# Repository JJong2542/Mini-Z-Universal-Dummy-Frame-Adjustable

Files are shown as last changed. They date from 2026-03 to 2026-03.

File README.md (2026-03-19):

# Mini-Z Universal Dummy Frame (90mm-102mm Adjustable)

Professional-grade adjustable dummy frame for Kyosho Mini-Z body fitting, painting, and display. This project provides high-precision engineering drawings for both CNC machining and 3D printing.

## 🚀 Key Features
- **Adjustable Wheelbase:** Supports 90mm, 94mm, 98mm, and 102mm setups.
- **Wide/Narrow Compatible:** Designed to verify fitment for both standard and wide-body kits (e.g., HRC Wide Body).
- **Manufacturing Ready:** Includes full technical drawings (PDF) with tolerances for AL6061 CNC machining.
- **Surface Finish:** Optimized for sanded black gloss anodizing.

## 📂 Project Structure
- `/3D Print`: Full set 3D Printed 'STL Format File' (Parts).
- `/STEP File`: Full set 3D Cad Data 'STEP Format File' (Part Data).
- `/Drawings`: Full set of technical drawings (Assembly & Part Drawings).
- `/Photos`: Verified 3D printed samples and body fitting examples (Toyota 86).

## 🛠 Specifications
- **Material:** AL6061 (Aluminum) or 3D Printing (PLA/PETG/Resin)
- **Hardware:** M2 Bolts & Taps
- **Compatibility:** All Kyosho Mini-Z AWD/FWD wheelbases

## 📸 Proof of Concept

| 94mm Setup (Toyota 86)_Top | 94mm Setup (Toyota 86)_Under |
| :---: | :---: |
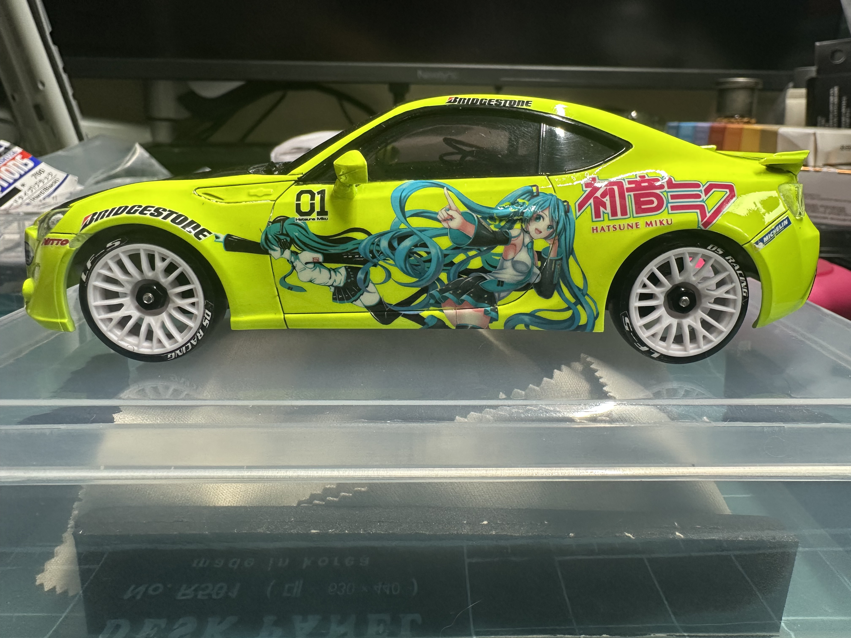
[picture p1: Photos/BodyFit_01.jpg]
Toyota 86 Fitting_01
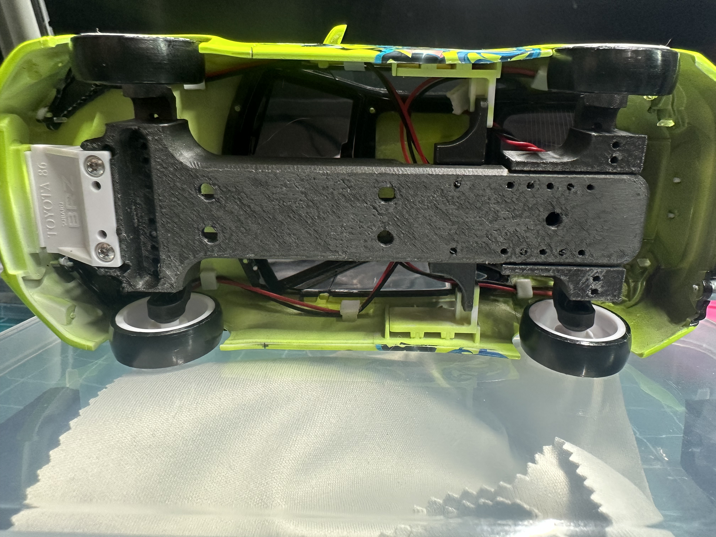
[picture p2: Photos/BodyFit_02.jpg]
Toyota 86 Fitting_02
|  |  |

| 3D Printed Sample_Top | 3D Printed Sample_Under |
| :---: | :---: |
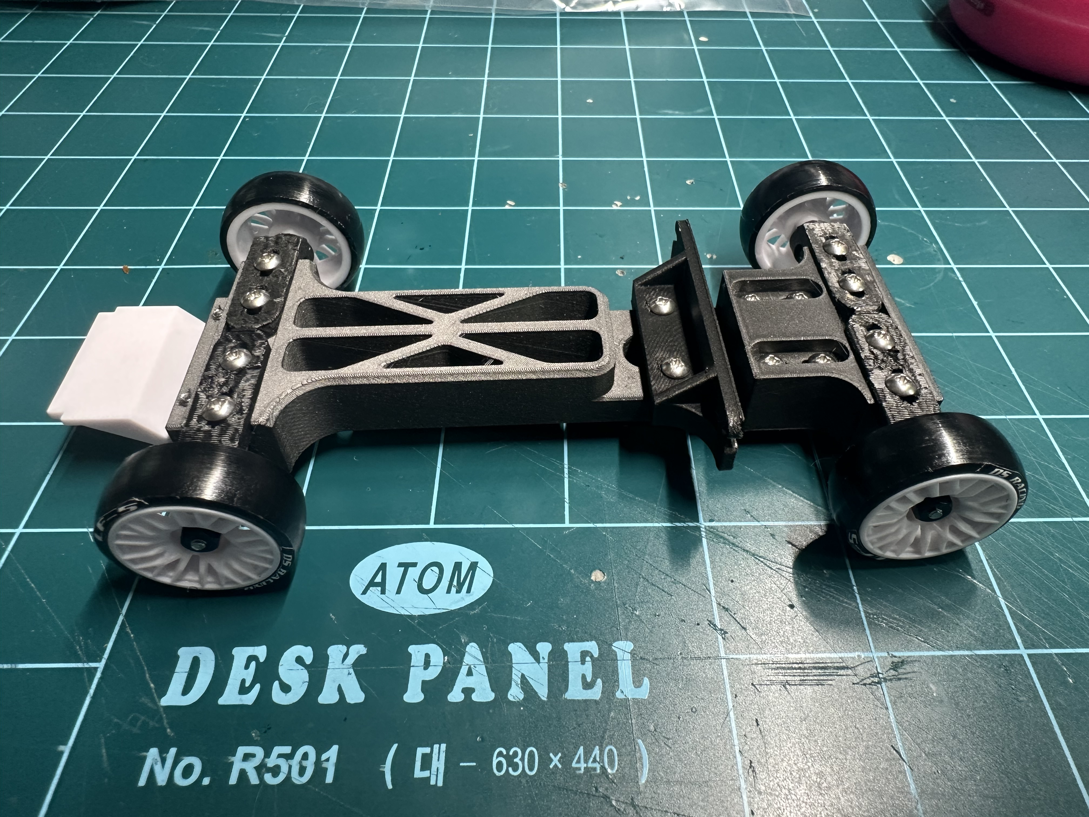
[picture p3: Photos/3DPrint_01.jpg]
3D Sample_01
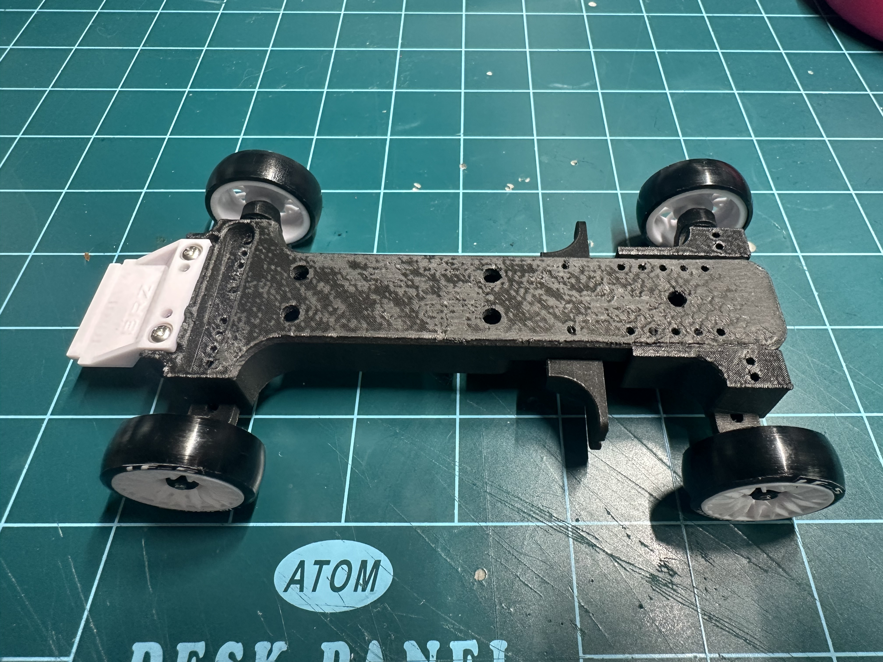
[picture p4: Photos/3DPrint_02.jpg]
3D Sample_02
|  |  |

### Functional Preview
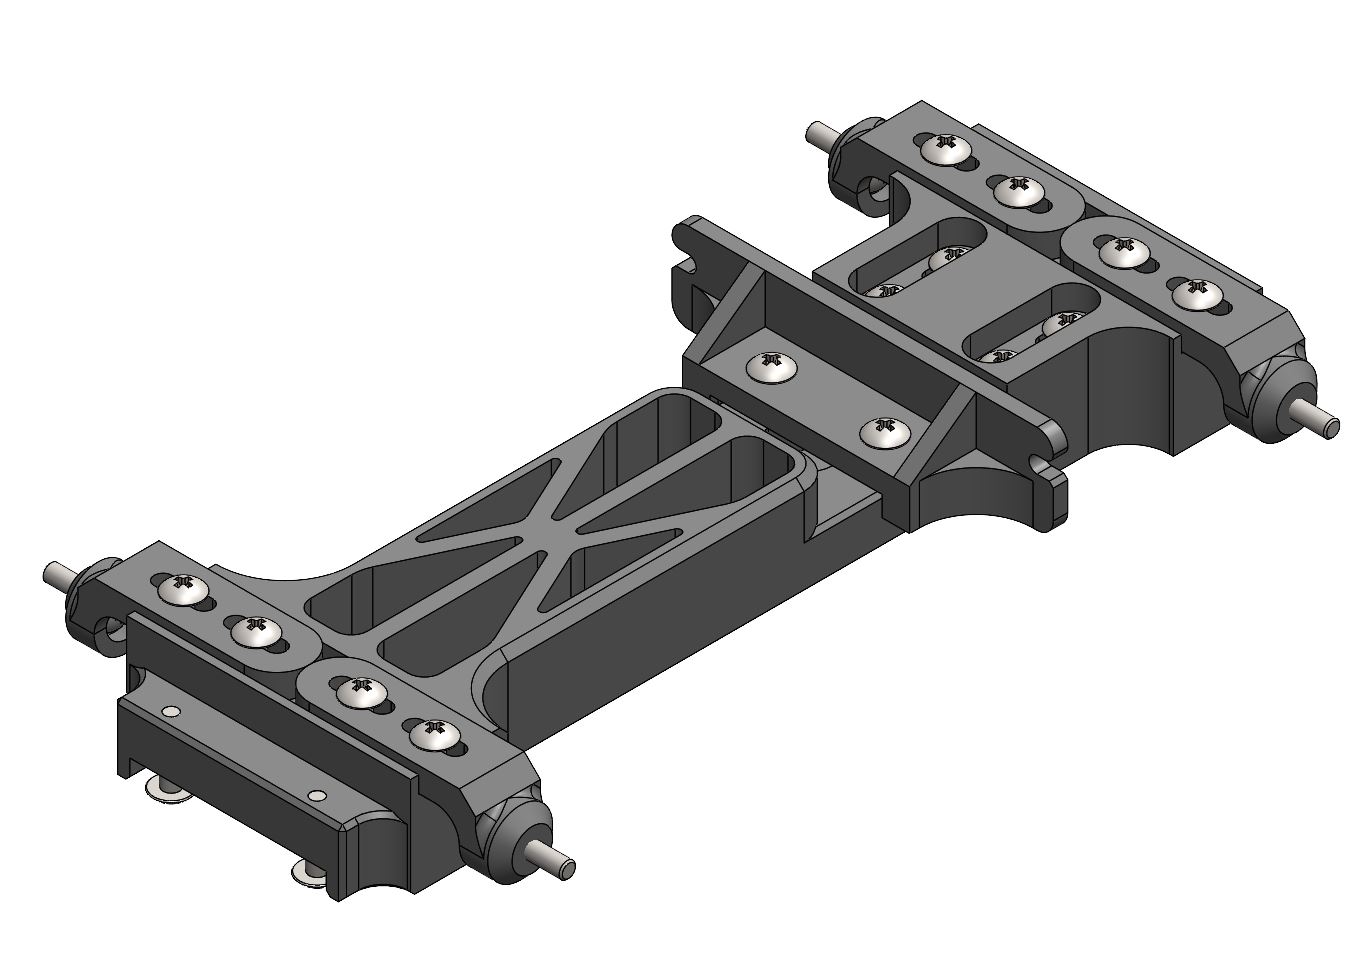
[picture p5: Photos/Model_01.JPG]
Dummy Frame Layout_01

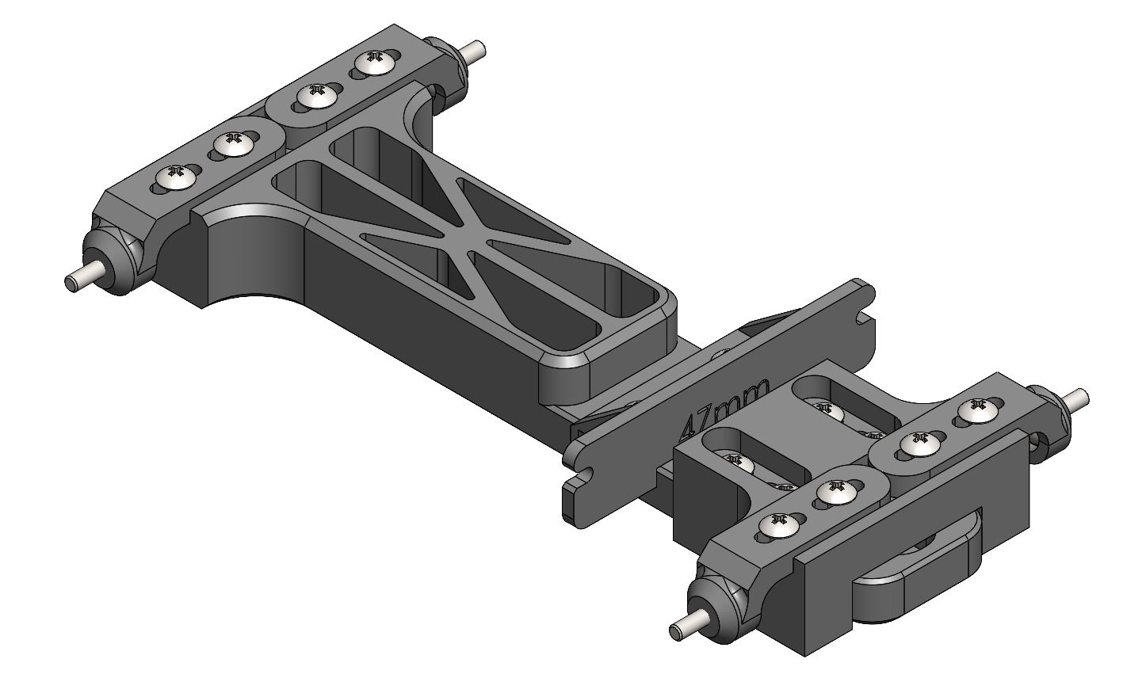
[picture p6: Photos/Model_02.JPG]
Dummy Frame Layout_02


## 🛠️ Assembly & Setup Guide

To help you get started quickly, please refer to the assembly layout and setup sheet below:

### 1. Assembly Layout
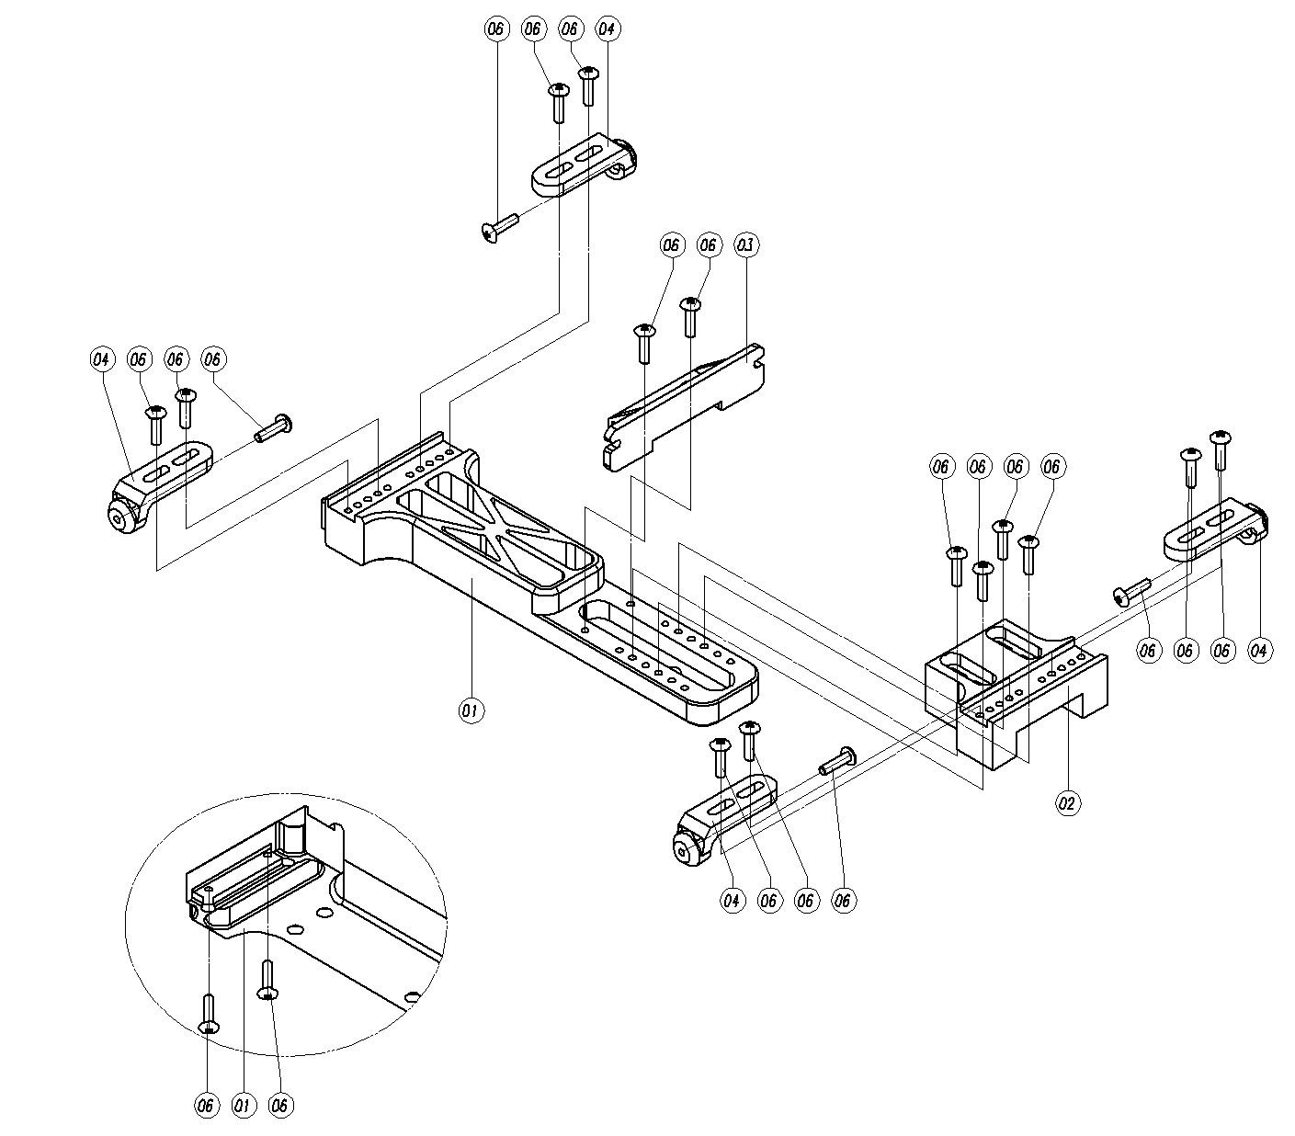
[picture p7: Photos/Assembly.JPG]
Assembly Guide

*Exploded view for clear component positioning.*
### 2. Parts List (BOM)
| Number | Part Name | Drawing Number | Quantity |
| :--- | :--- | :--- | :--- |
| 1 | **Main Body** | `F01-0002-01` | 1 |
| 2 | **Rear Wheel Mount** | `F01-0003-01` | 1 |
| 3 | **Body Mount** | `F01-0004-01` | 1 |
| 4 | **Wheel Hub** | `F01-0001-01` | 4 |
| 5 | **Post** | `F01-0005-01` | 3 |
| 6 | **Screw** | `Truss M2 X 8L` | 20 |

> [!NOTE]
> All mechanical parts are designed for M2 screws. For 3D printing, it is recommended to have a 2.0mm tap or drill bit ready for clean assembly.

### 3. Setup Sheet (Wheelbase & Width)
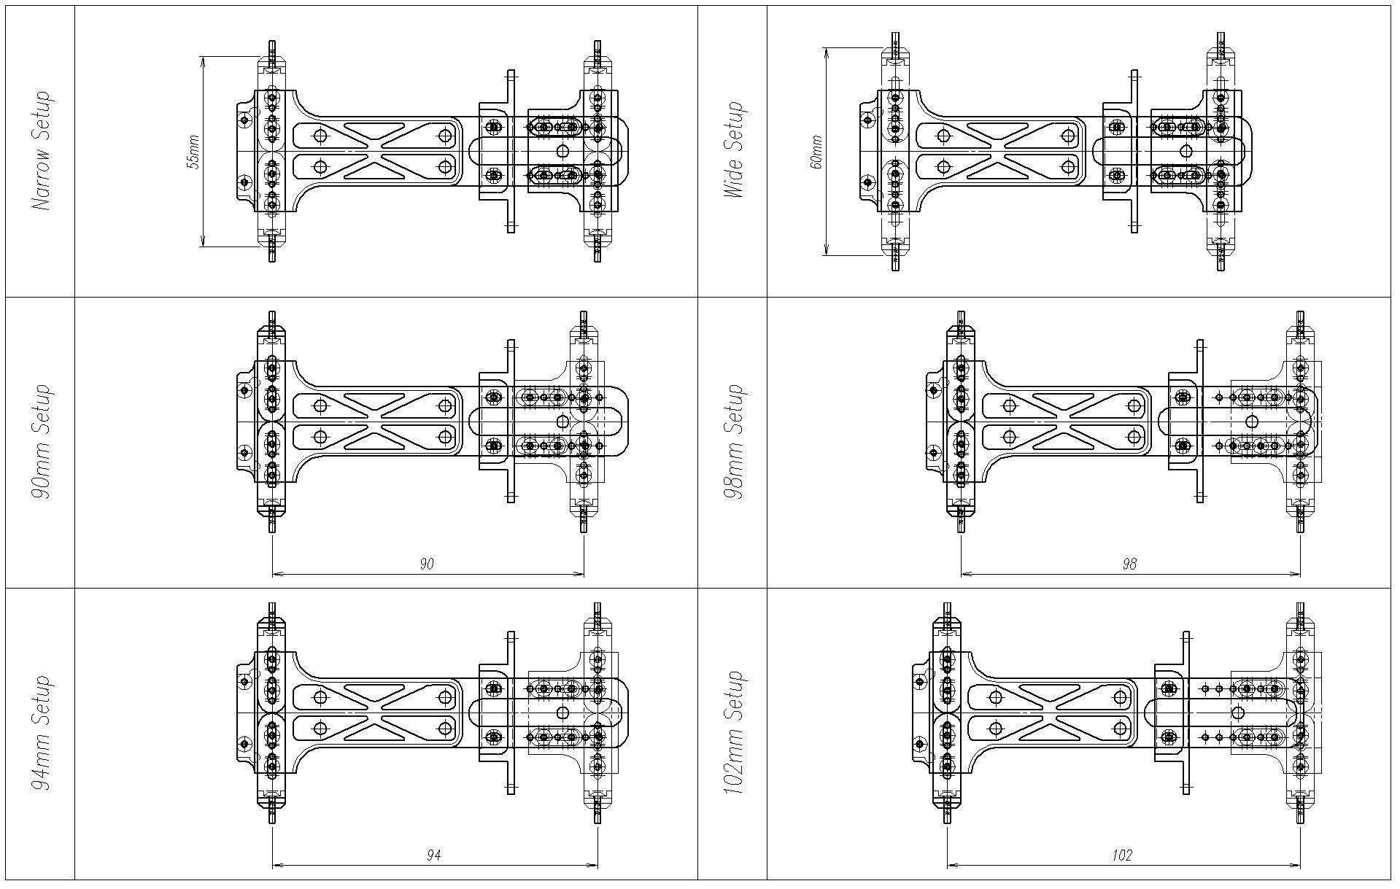
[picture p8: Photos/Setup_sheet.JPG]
Setup Sheet

*Quick reference for 90mm, 94mm, 98mm, and 102mm configurations.*

## ⚖️ License
This project is shared for the Mini-Z community. Feel free to use, modify, and share.

---
**Designed by JWKim**
*Precision Mechanical Design for RC Enthusiasts*

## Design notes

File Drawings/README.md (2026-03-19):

## 📄 Available Drawings
All drawings are provided in **PDF format** with full dimensions and tolerances:
- `F01-1001-01`: Assembly Drawing (Standard & ISO)
- `F01-0001-01`: Wheel Hub
- `F01-0002-01`: Main Base
- `F01-0003-01`: Rear Wheel Mount
- `F01-0004-01`: Body Mount
- `F01-0005-01`: Post

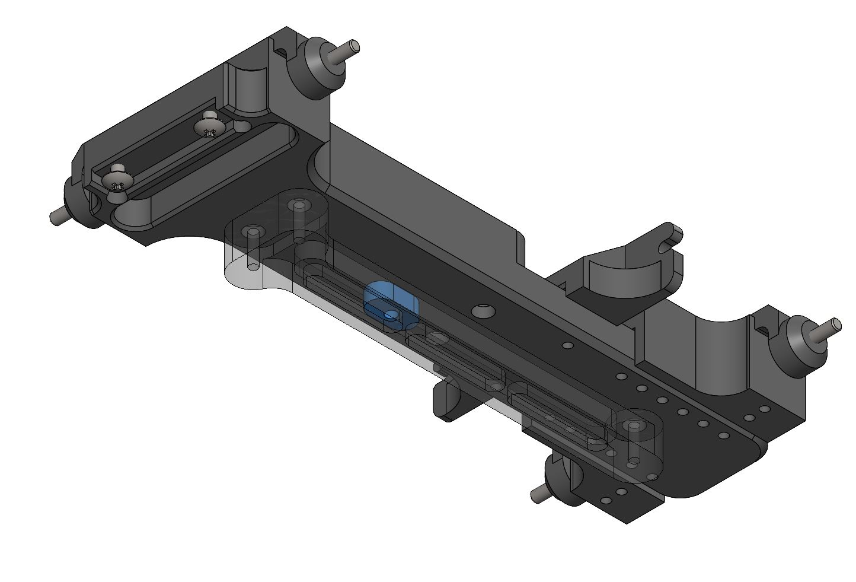
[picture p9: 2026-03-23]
Photos/Model_04.JPG

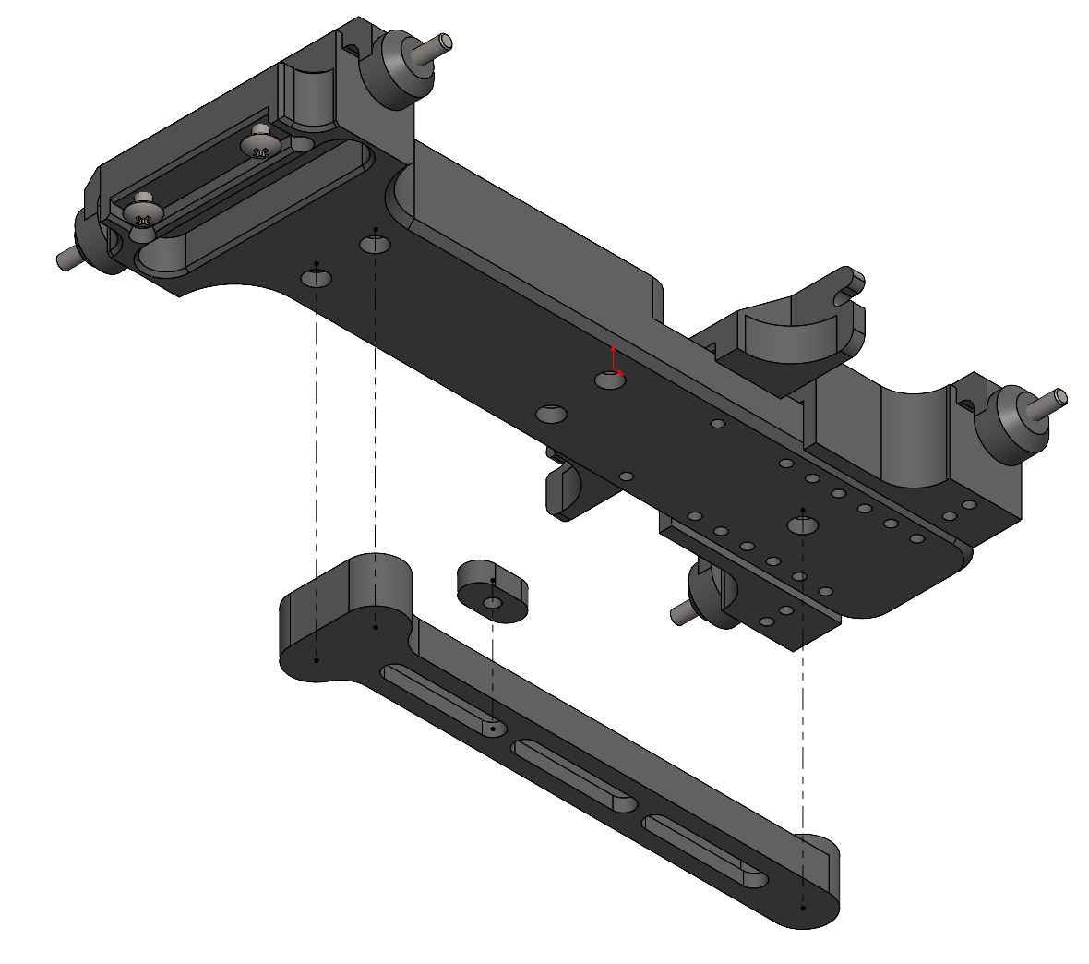
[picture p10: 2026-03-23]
Photos/Model_03.JPG

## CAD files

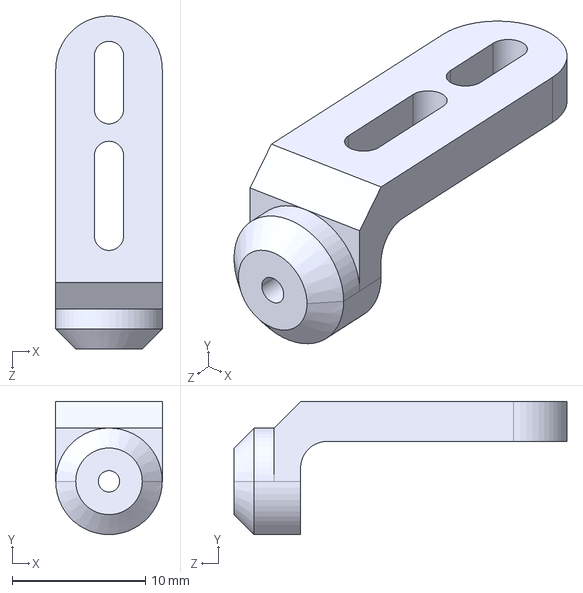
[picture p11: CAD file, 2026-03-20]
STEP File/F01-0001-02.STEP
8.00 x 10.0 x 25.0 mm

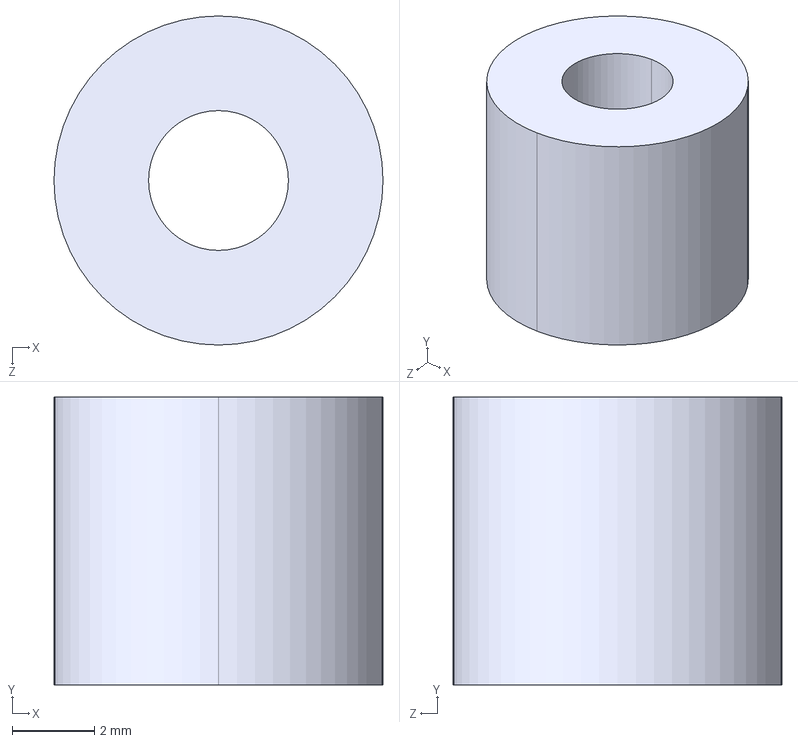
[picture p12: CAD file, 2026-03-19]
STEP File/F01-0005-01.STEP
8.00 x 7.00 x 8.00 mm

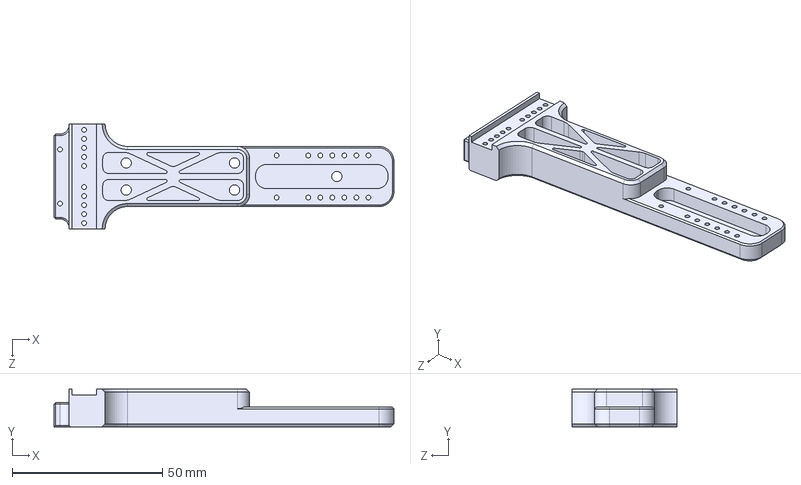
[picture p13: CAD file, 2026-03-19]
STEP File/F01-0002-01.STEP
113.0 x 12.5 x 35.0 mm

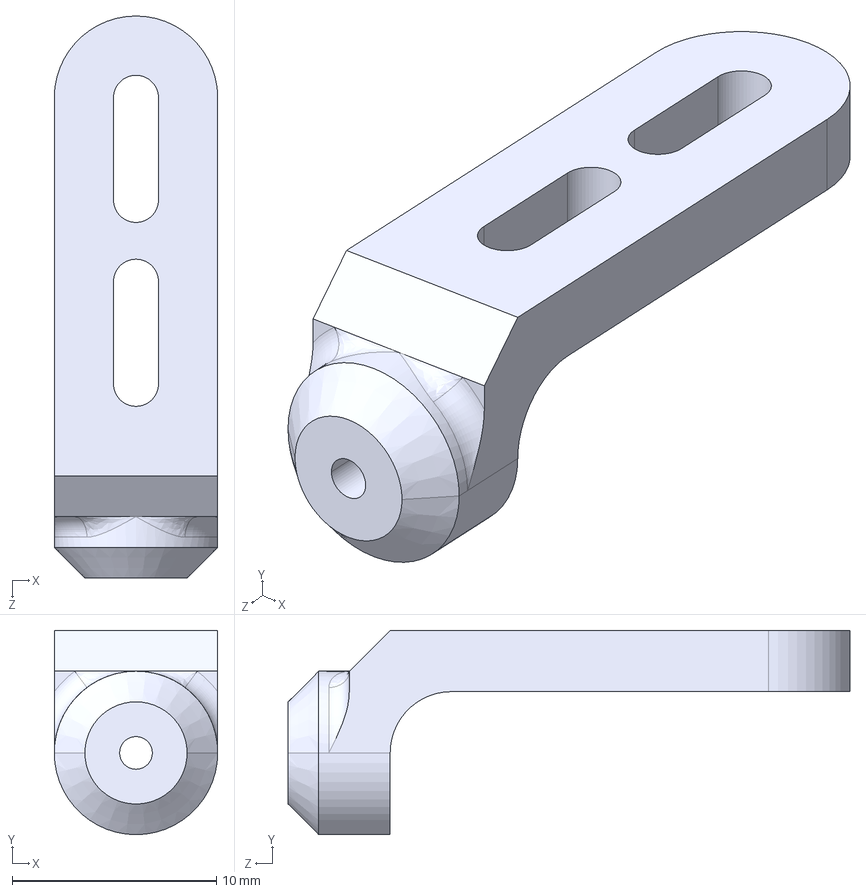
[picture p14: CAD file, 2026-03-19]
STEP File/F01-0001-01.STEP
8.00 x 10.0 x 27.5 mm

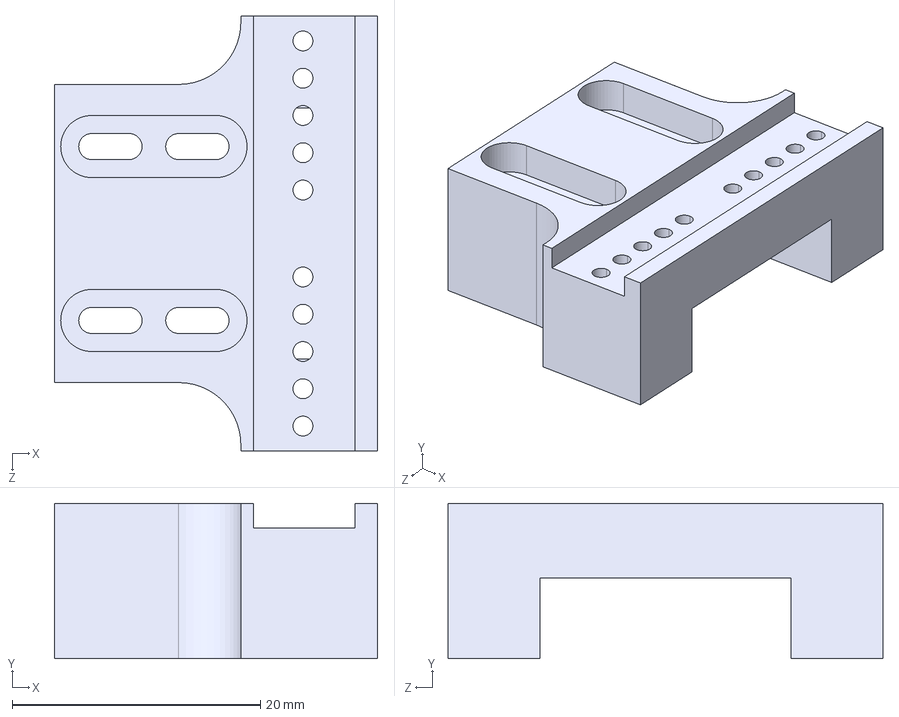
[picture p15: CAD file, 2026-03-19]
STEP File/F01-0003-01.STEP
26.0 x 12.5 x 35.0 mm

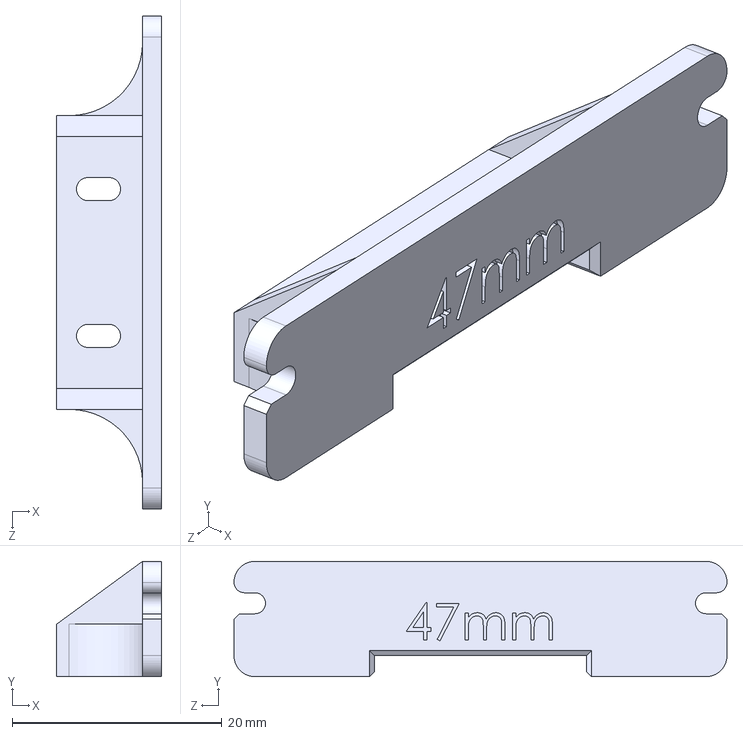
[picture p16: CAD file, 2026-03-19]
STEP File/F01-0004-03_47mm.STEP
10.0 x 11.0 x 47.0 mm

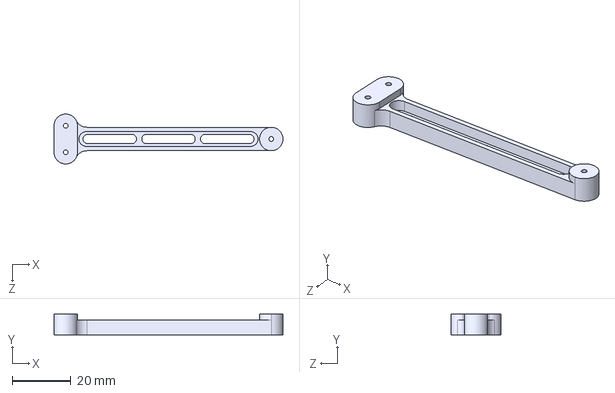
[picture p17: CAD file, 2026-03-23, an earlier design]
STEP File/Legacy_1.2/F01-0006-01.STEP
78.0 x 7.00 x 17.0 mm

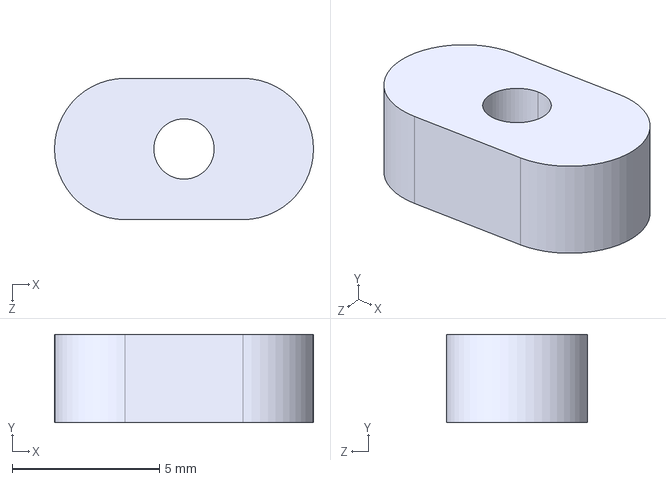
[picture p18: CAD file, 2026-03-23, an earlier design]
STEP File/Legacy_1.2/F01-0005-02.STEP
8.80 x 3.00 x 4.80 mm

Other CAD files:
3D_Print/F01-0001-01.STL
3D_Print/F01-0001-02.STL
3D_Print/F01-0002-01.STL
3D_Print/F01-0003-01.STL
3D_Print/F01-0004-03_47mm.STL
3D_Print/F01-0005-01.STL
3D_Print/Legacy_1.1/F01-0001-01.STL
3D_Print/Legacy_1.1/F01-0005-01.STL
3D_Print/Legacy_1.2/F01-0001-02.STL
3D_Print/Legacy_1.2/F01-0002-01.STL
3D_Print/Legacy_1.2/F01-0003-01.STL
3D_Print/Legacy_1.2/F01-0004-03_47mm.STL
3D_Print/Legacy_1.2/F01-0005-02.STL
3D_Print/Legacy_1.2/F01-0006-01.STL

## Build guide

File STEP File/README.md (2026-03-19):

## 📐 CAD Collaboration (STEP Files)
For advanced users and engineers, I have included **STEP files** to allow for easy modification and integration. 

- **Full Assembly Control:** Use the `.step` files to verify fits in your own CAD environment.
- **Customization:** Feel free to modify the design to create your own custom mounts or specialized jigs.
- **High Compatibility:** Compatible with all major CAD software including Fusion 360, SolidWorks, CATIA, and Rhino.

> [!TIP]
> If you create a derivative work or an improved version based on these STEP files, I’d love to see it! Please feel free to share your results with the community.

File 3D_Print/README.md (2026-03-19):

## 🖨️ 3D Printing (STL Files)
For those who don't have access to CNC machining, I've provided **STL files** for 3D printing.

### Recommended Print Settings
- **Material:** PETG or ABS (Recommended for durability), PLA+ is also fine.
- **Infill:** 40% or higher (Grid or Gyroid pattern for strength).
- **Wall Line Count:** 3-4 layers.
- **Support:** Required for some parts (Main Base and Rear Wheel Mount).
- **Layer Height:** 0.16mm - 0.2mm.

### Assembly Note
- Since 3D prints have slight shrinkage, you might need to clean up the holes with a **2mm drill bit** or a **reamer** for a perfect fit with the M2 bolts.
> **Tip:** You can view the 3D models directly in your browser! Just click on any `.stl` file in the `STL` folder to rotate and inspect the design before downloading.

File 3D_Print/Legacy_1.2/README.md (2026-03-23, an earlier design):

This folder contains data from the previous version, 1.2.

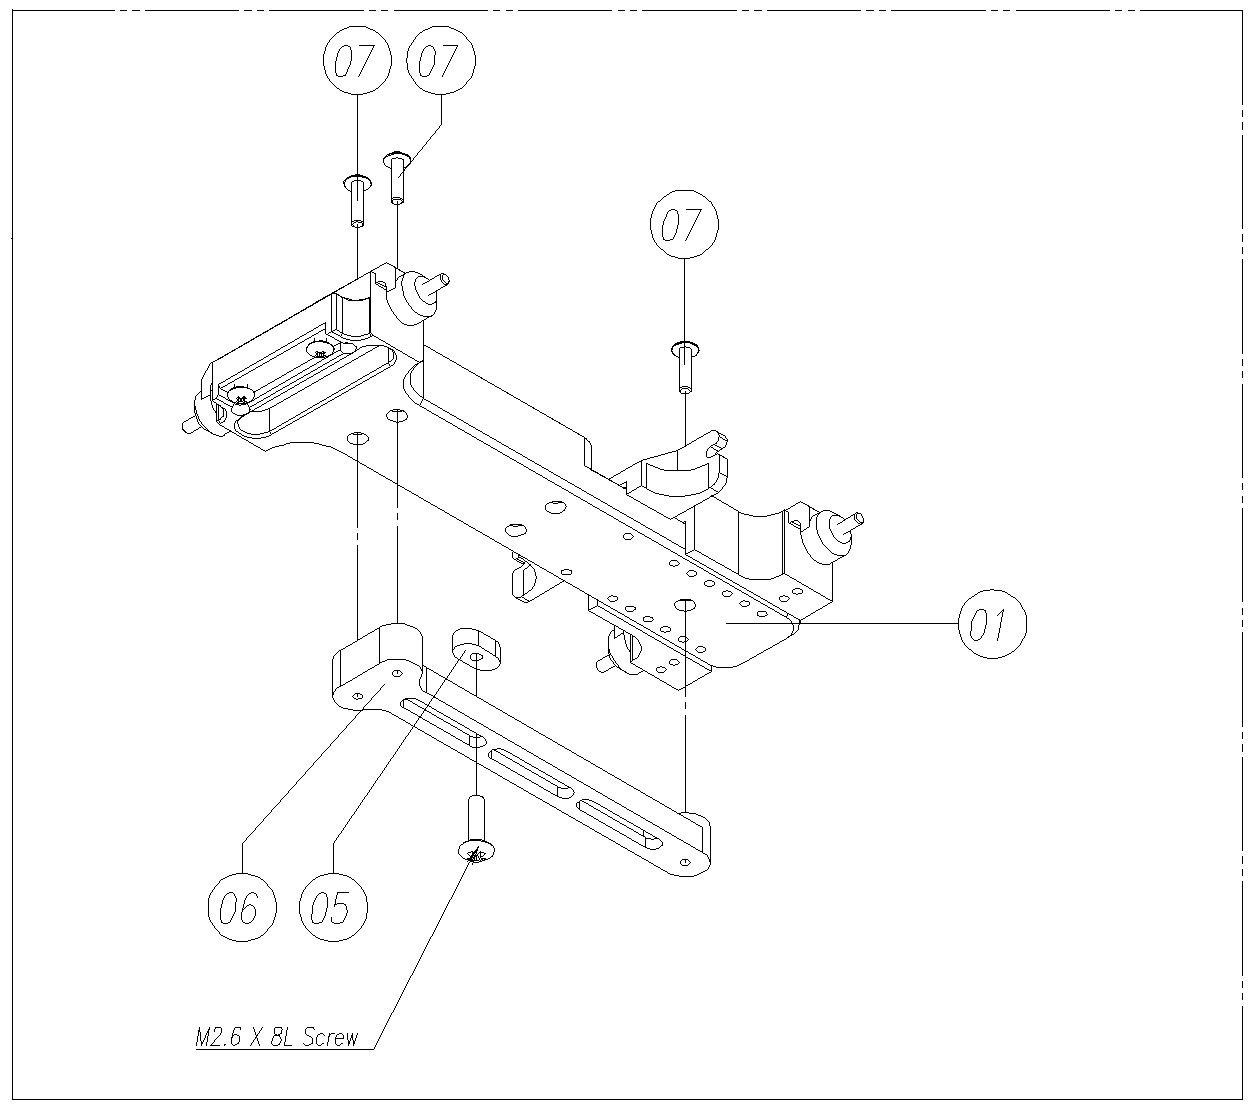
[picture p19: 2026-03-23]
Photos/Setup_sheet_02.JPG

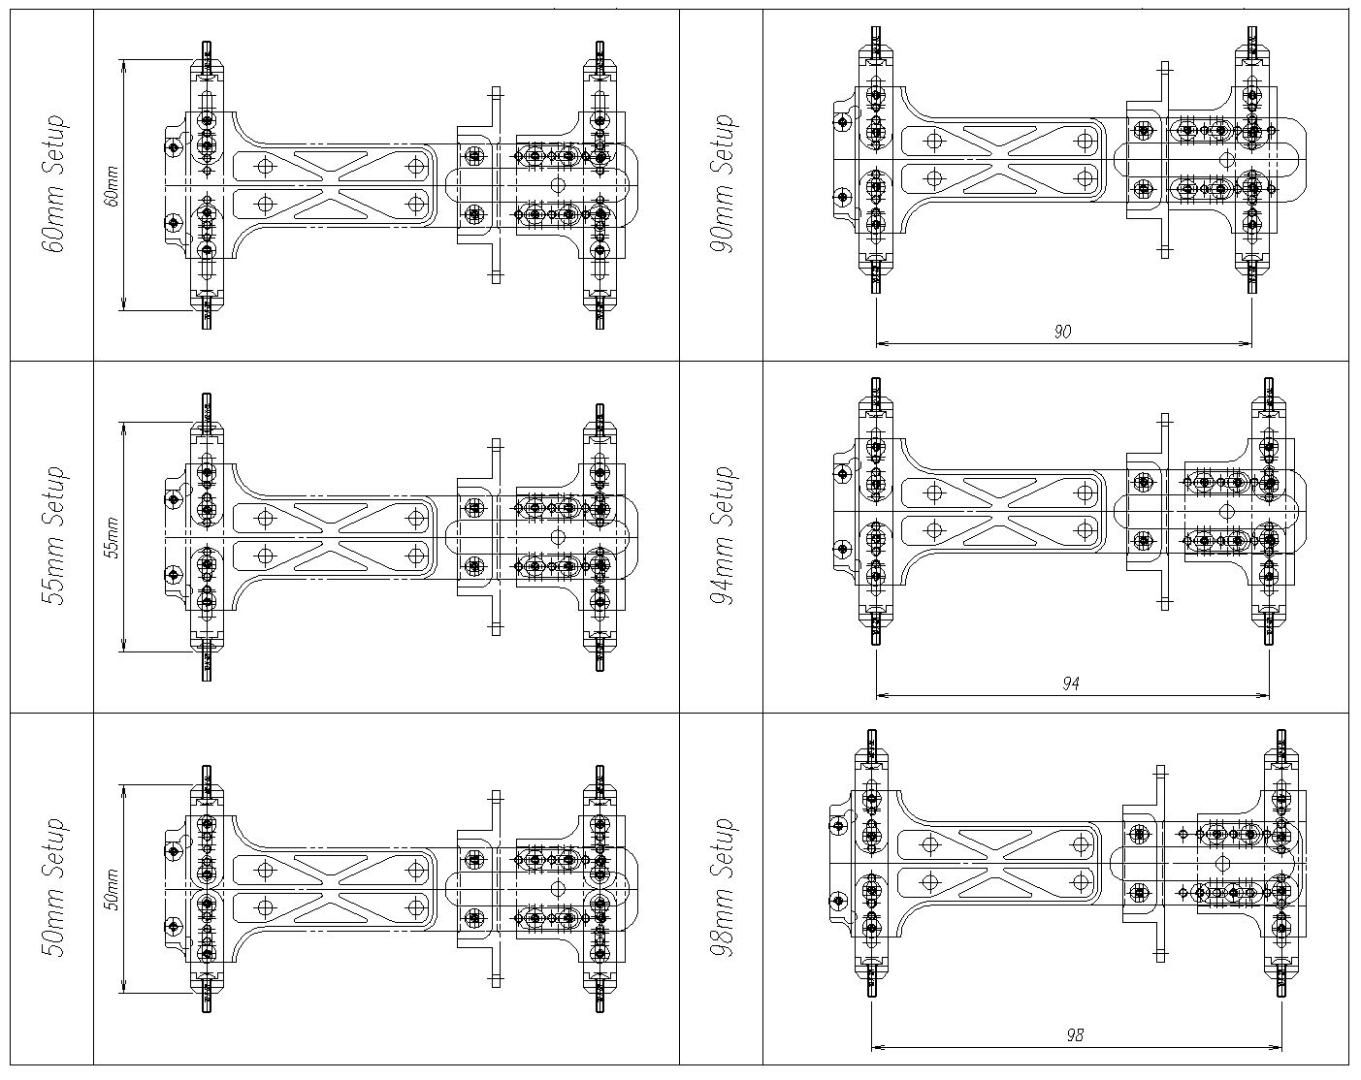
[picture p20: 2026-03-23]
Photos/Setup_sheet_01.JPG

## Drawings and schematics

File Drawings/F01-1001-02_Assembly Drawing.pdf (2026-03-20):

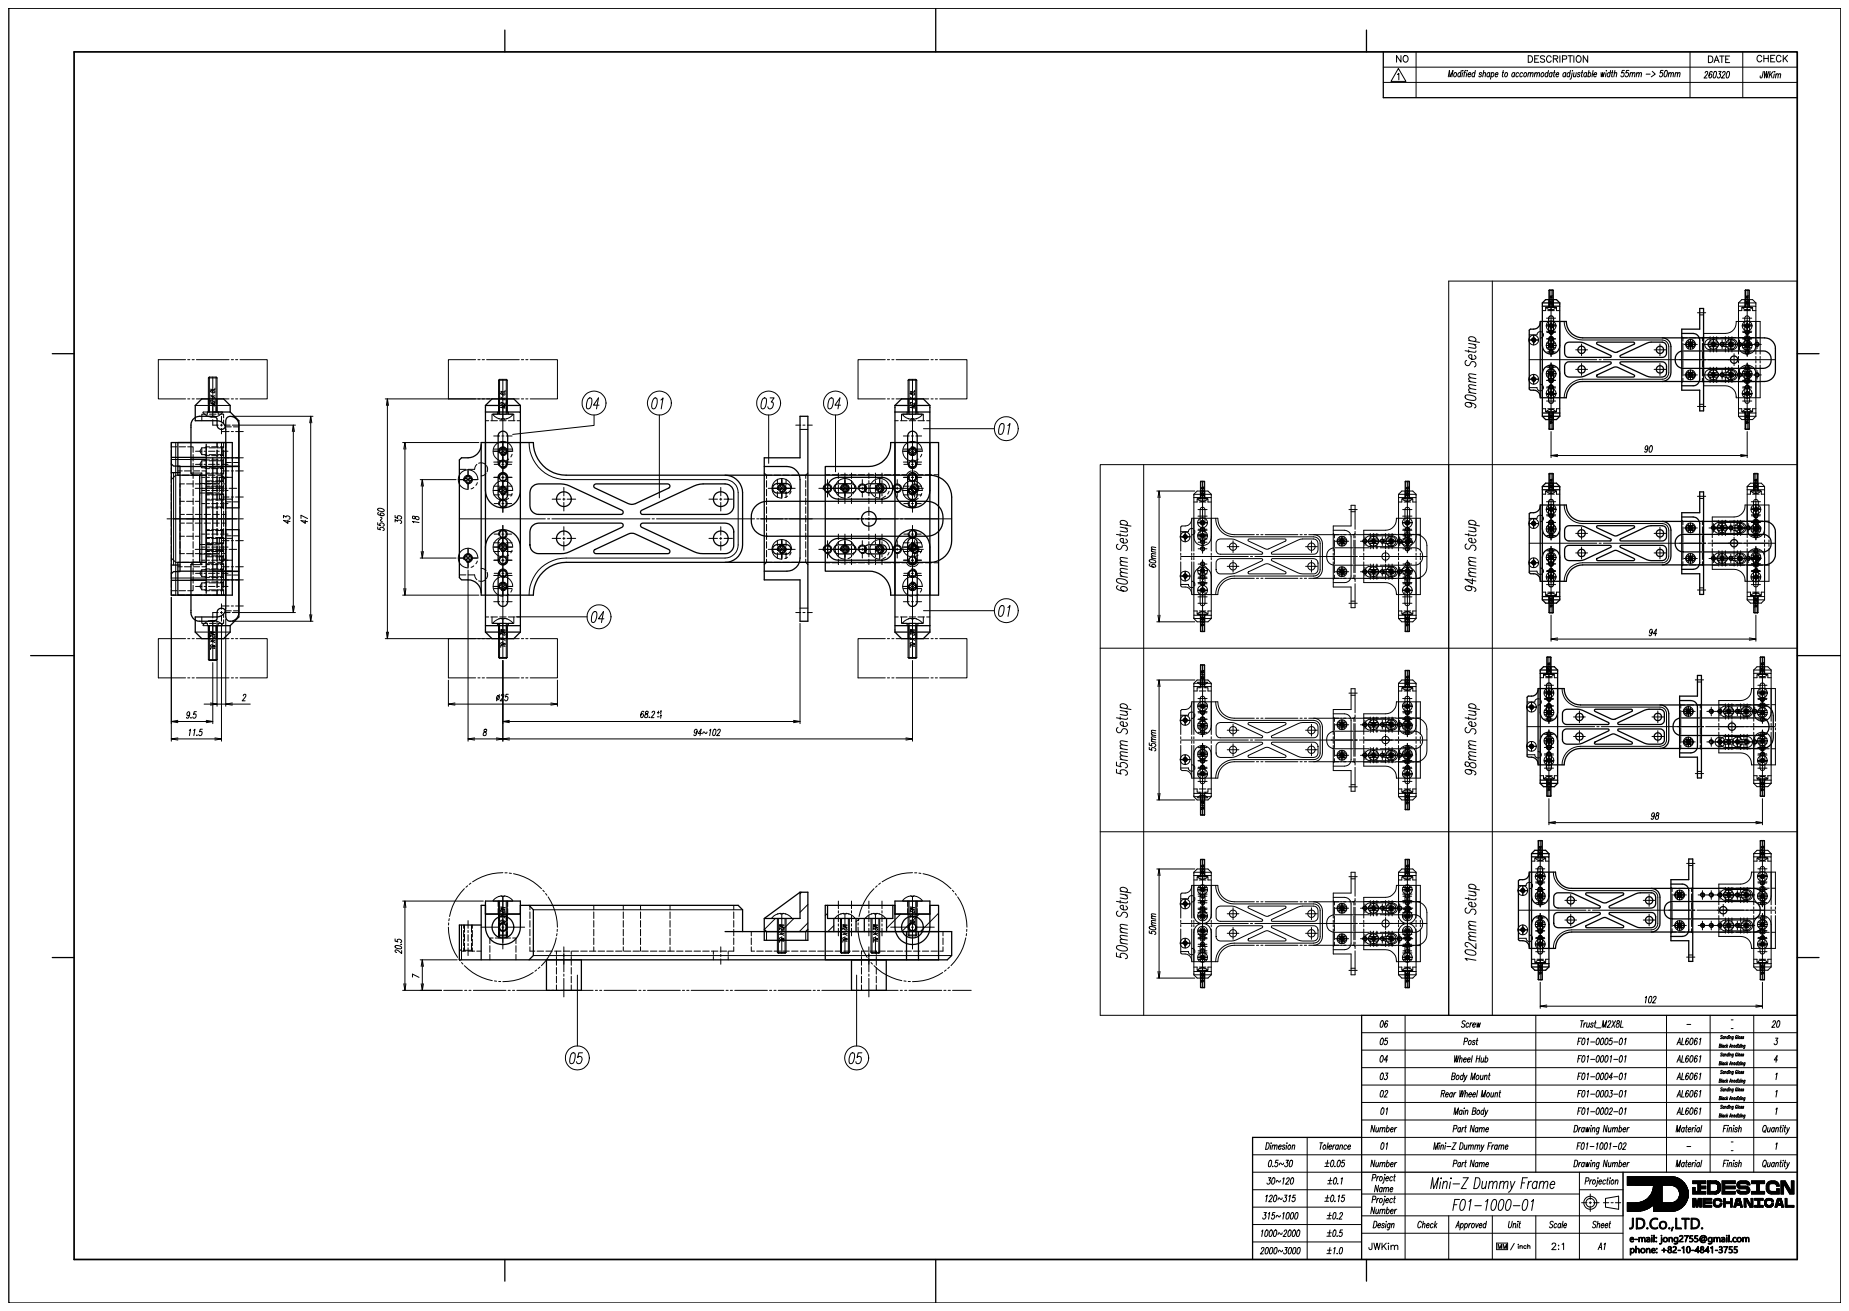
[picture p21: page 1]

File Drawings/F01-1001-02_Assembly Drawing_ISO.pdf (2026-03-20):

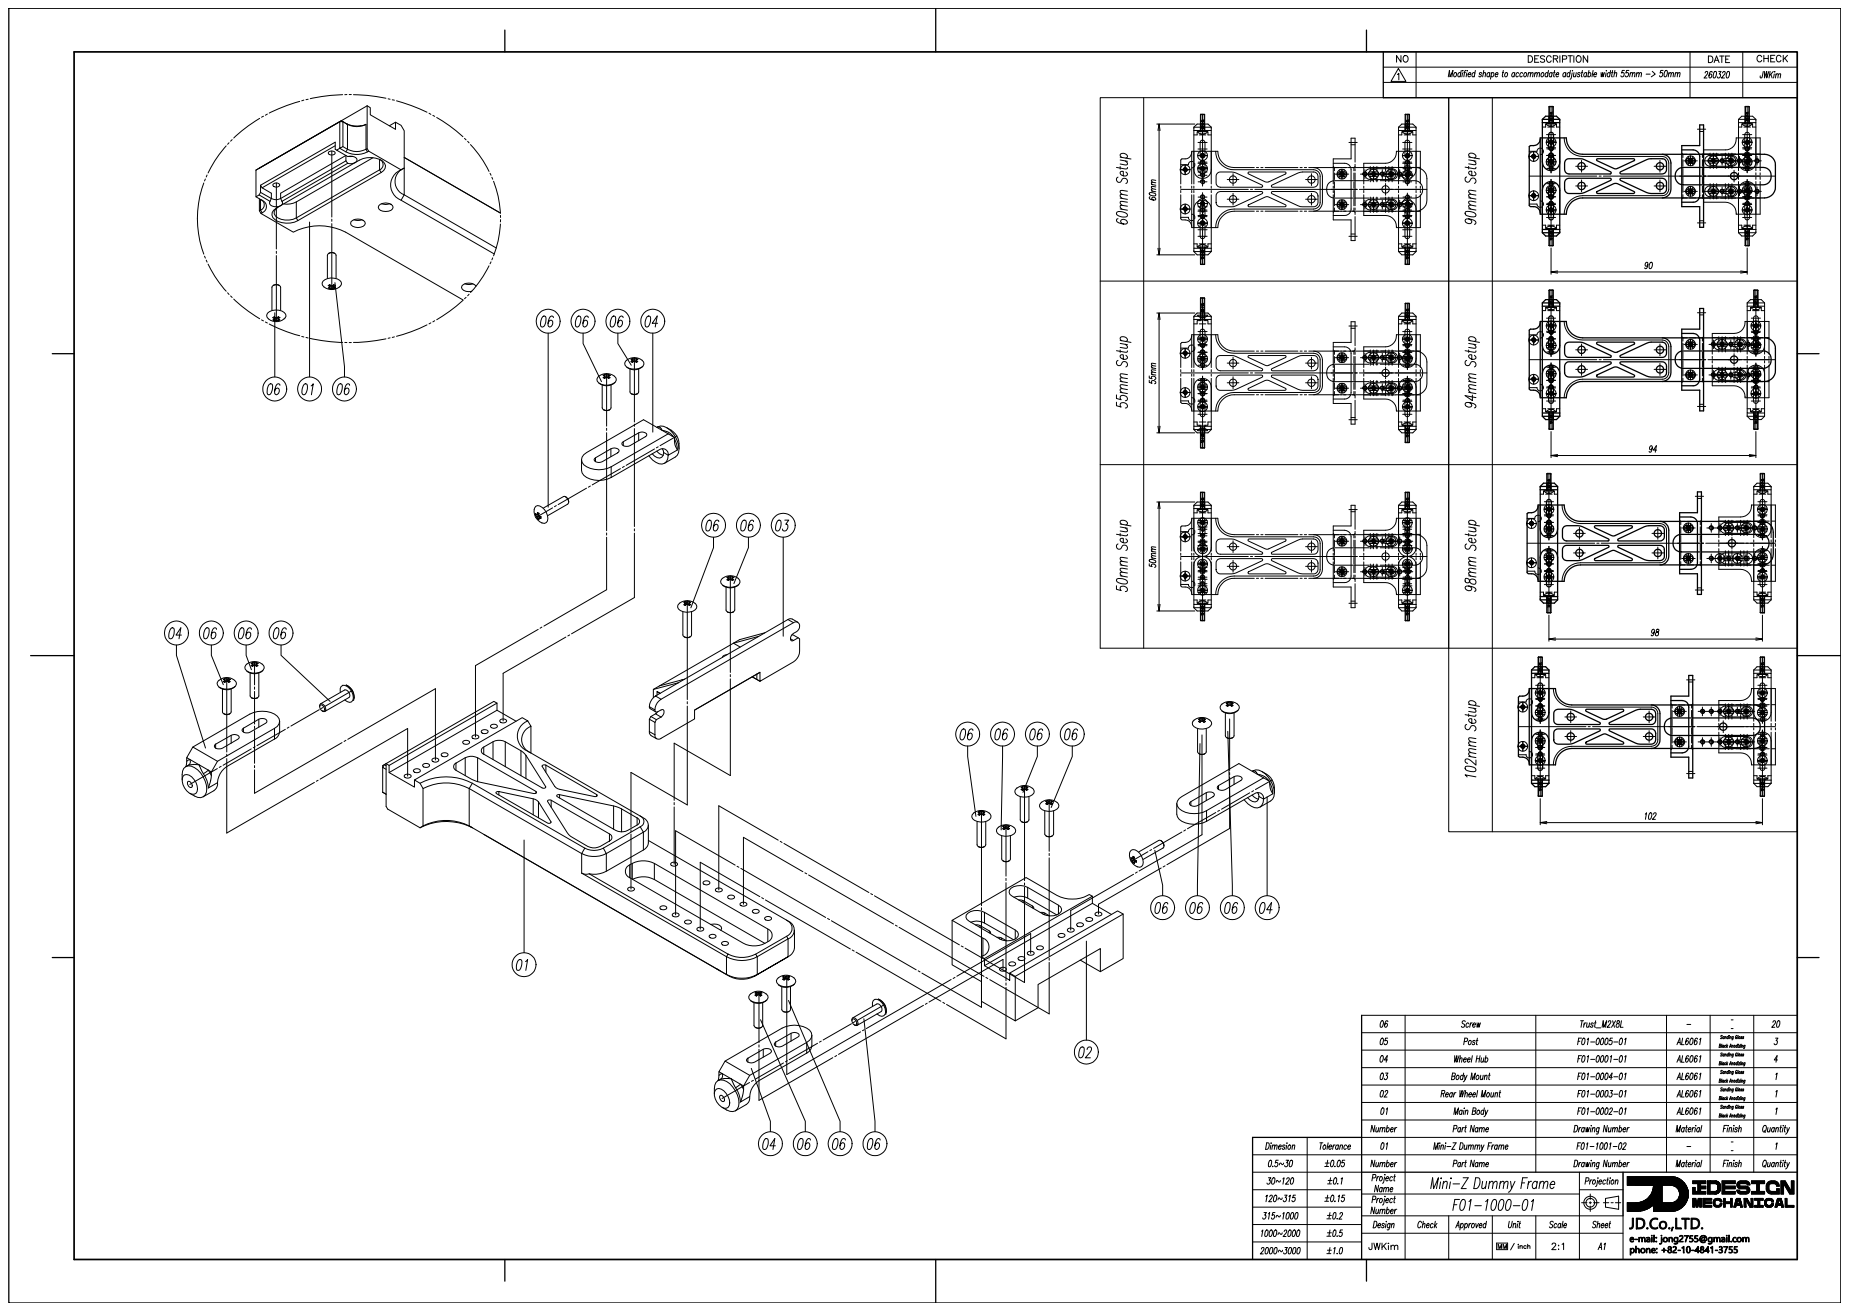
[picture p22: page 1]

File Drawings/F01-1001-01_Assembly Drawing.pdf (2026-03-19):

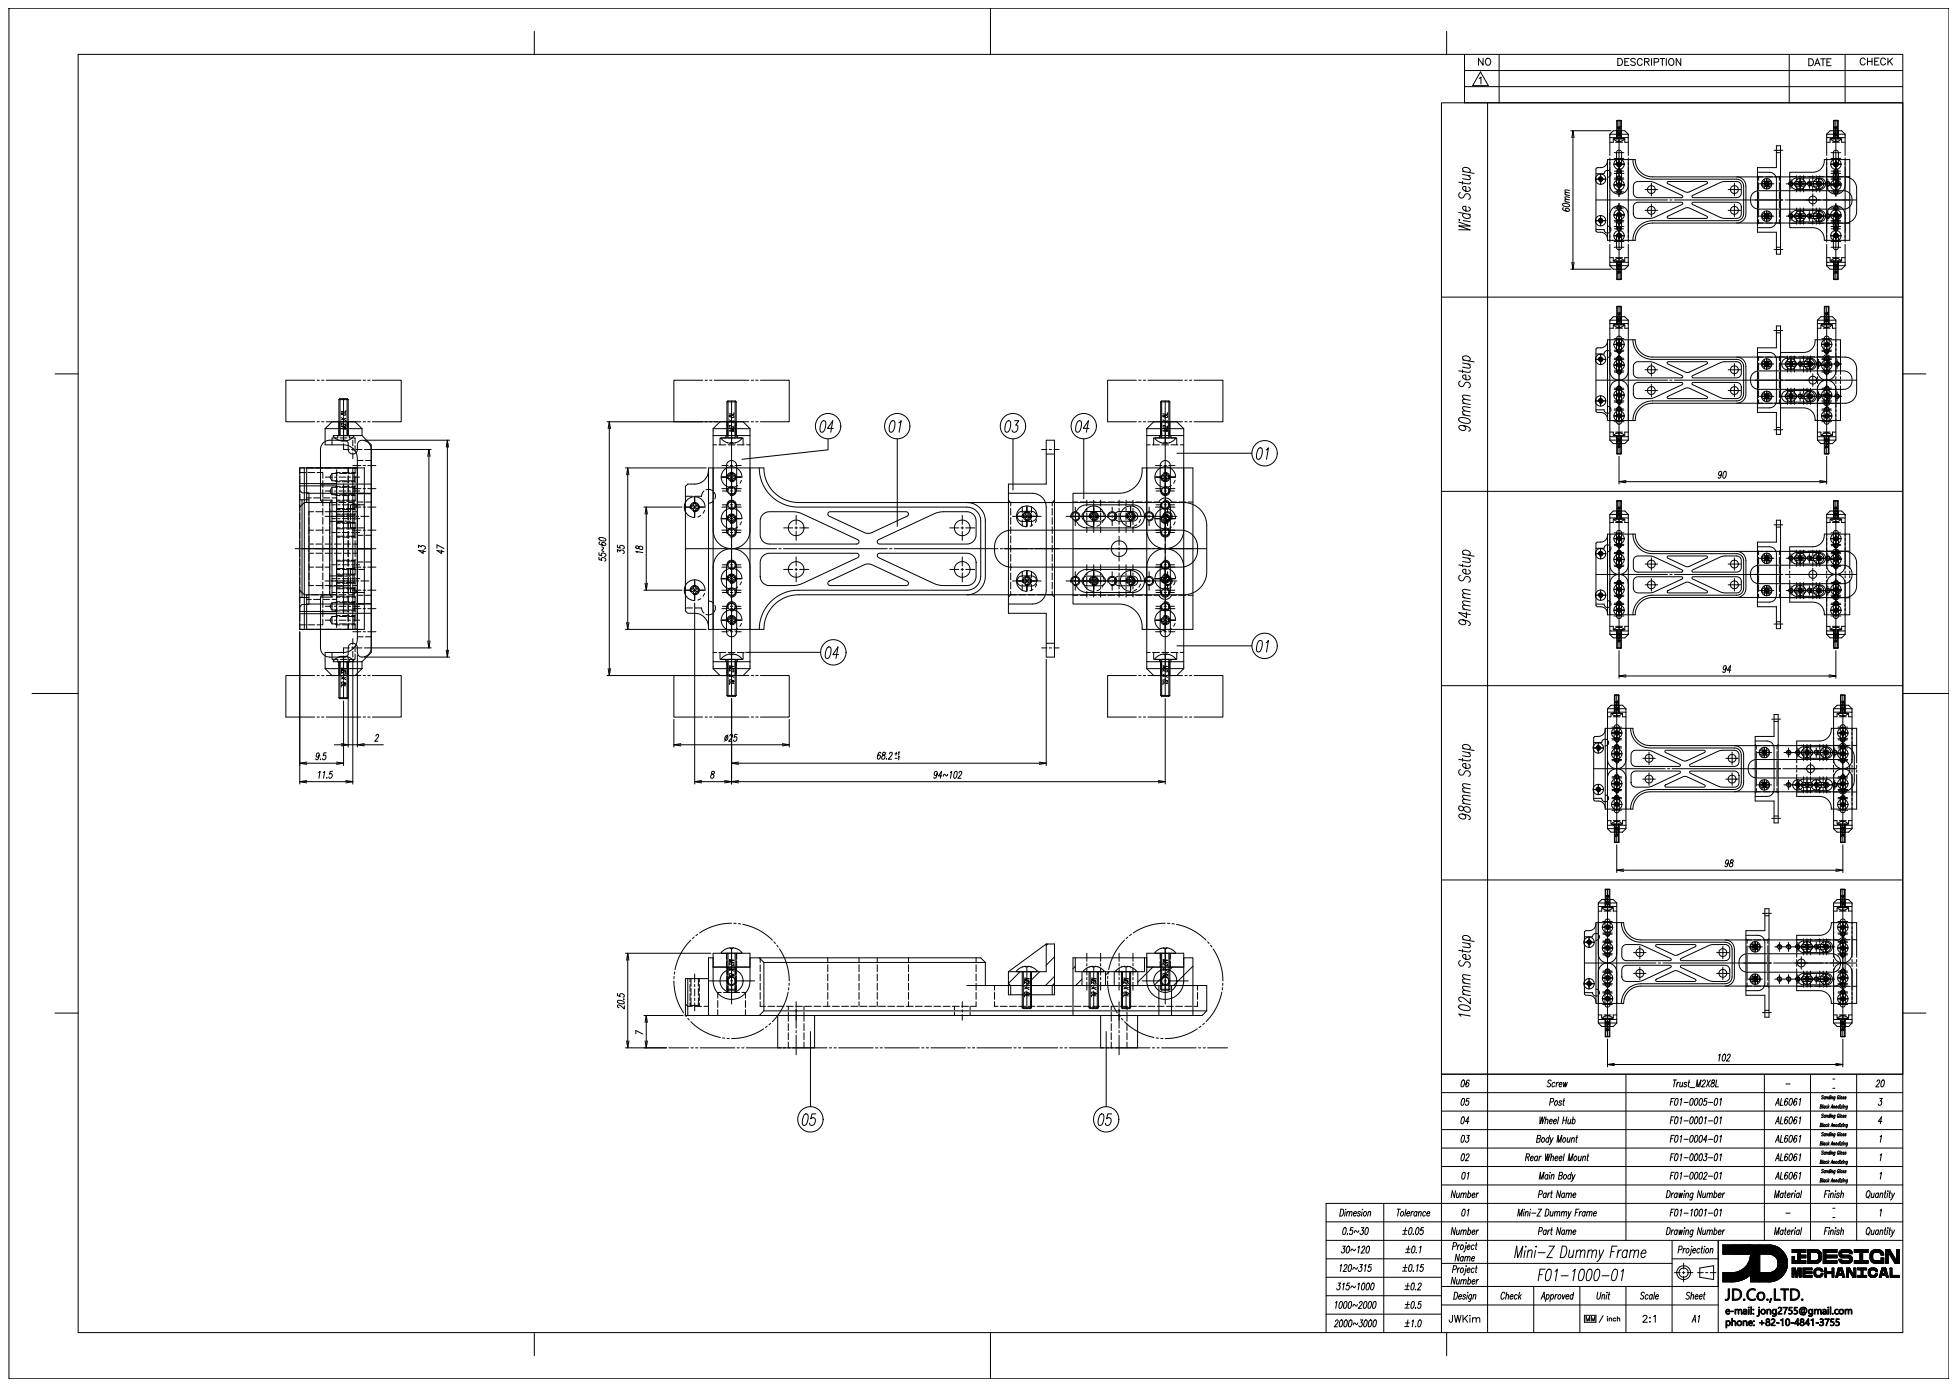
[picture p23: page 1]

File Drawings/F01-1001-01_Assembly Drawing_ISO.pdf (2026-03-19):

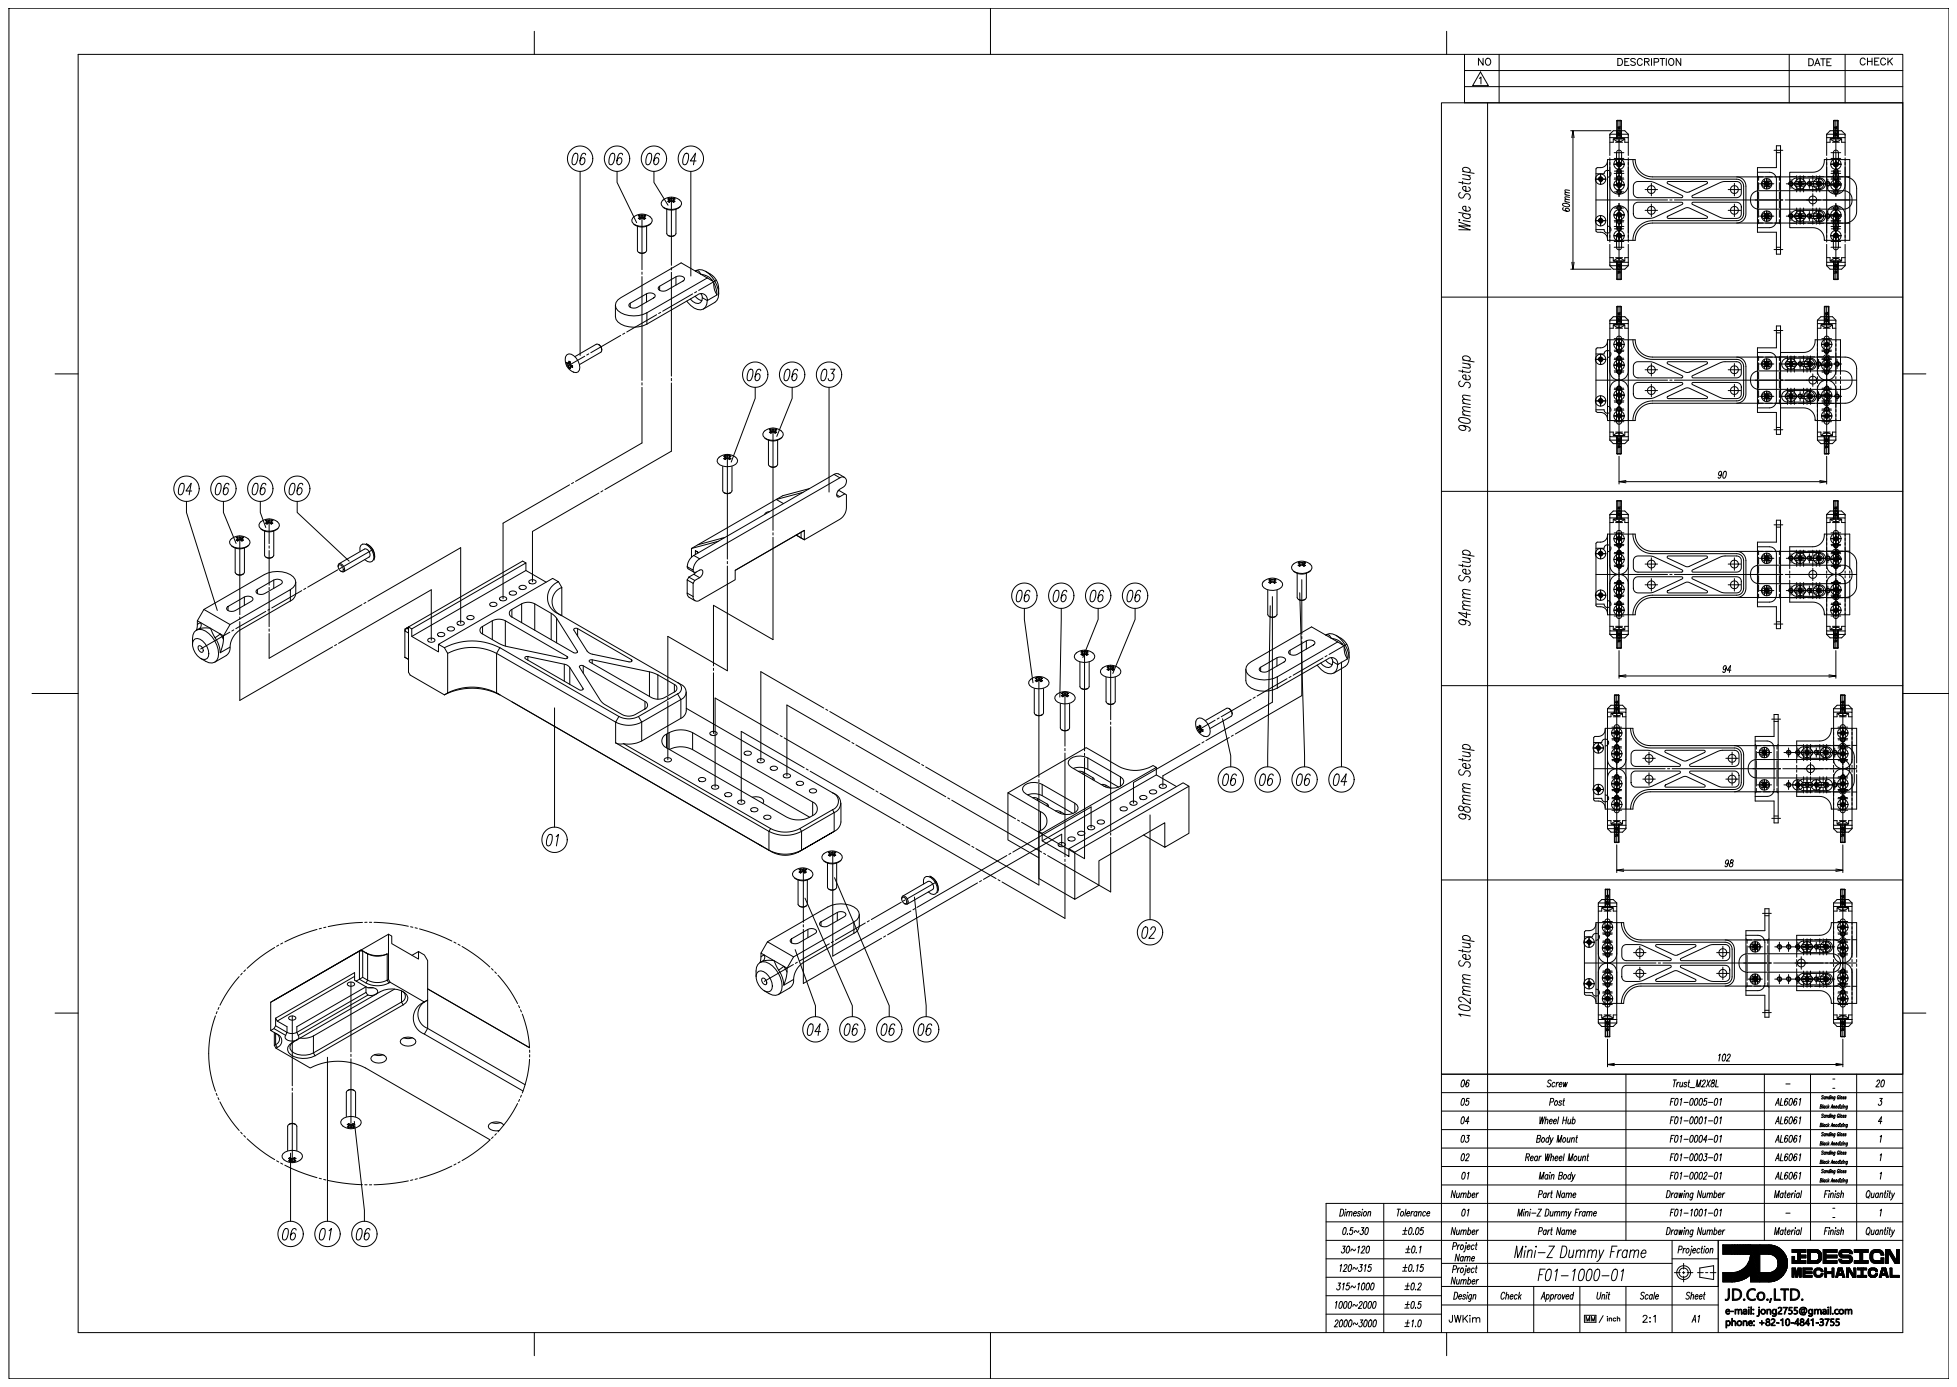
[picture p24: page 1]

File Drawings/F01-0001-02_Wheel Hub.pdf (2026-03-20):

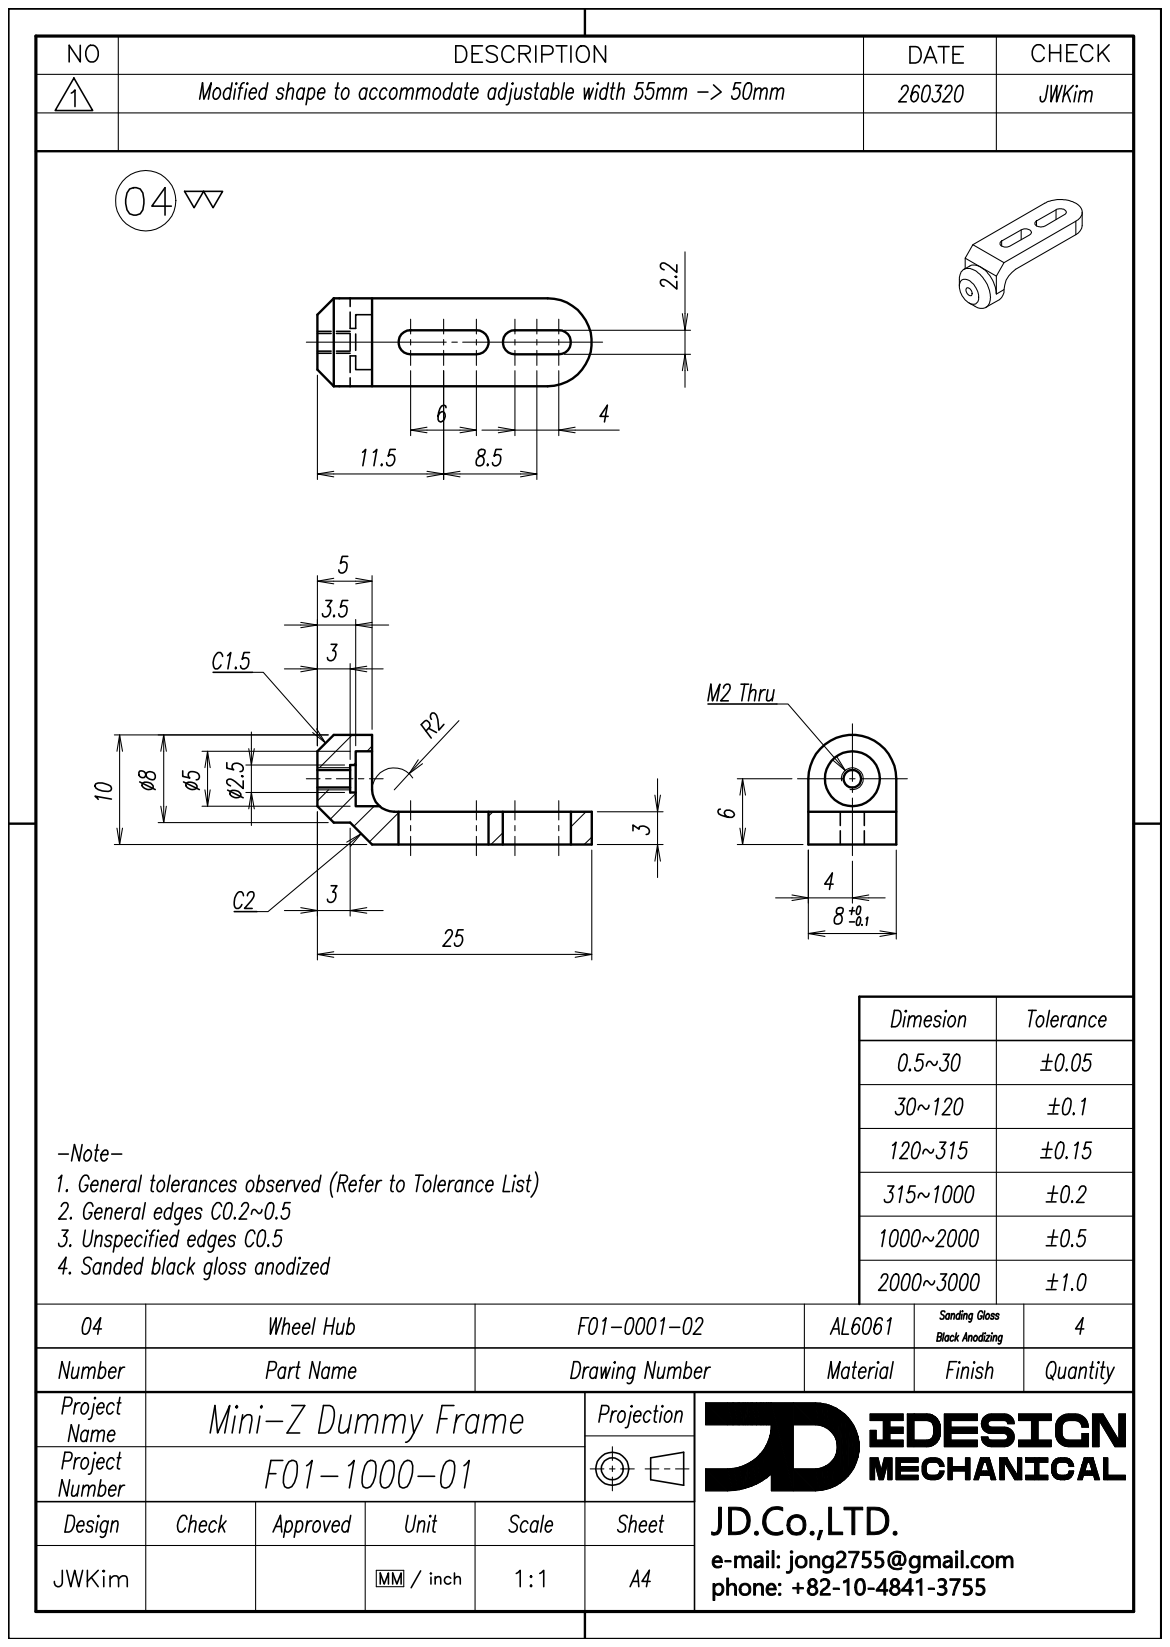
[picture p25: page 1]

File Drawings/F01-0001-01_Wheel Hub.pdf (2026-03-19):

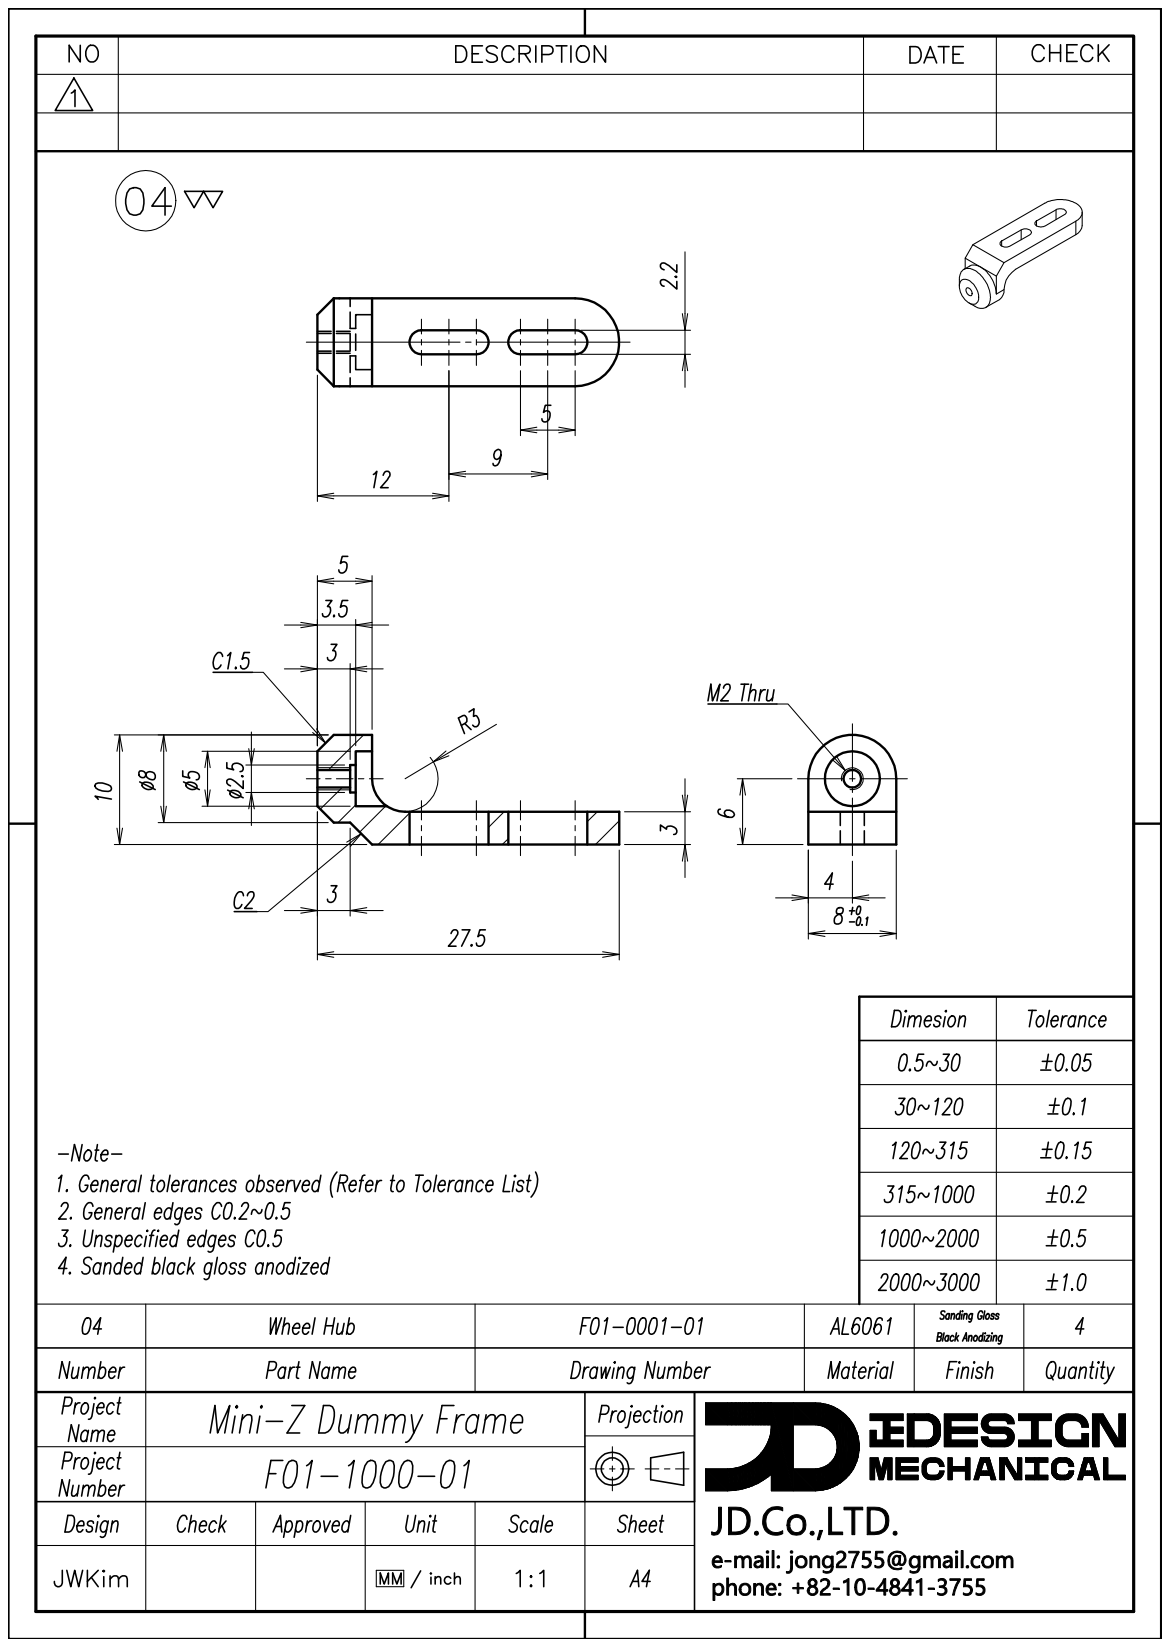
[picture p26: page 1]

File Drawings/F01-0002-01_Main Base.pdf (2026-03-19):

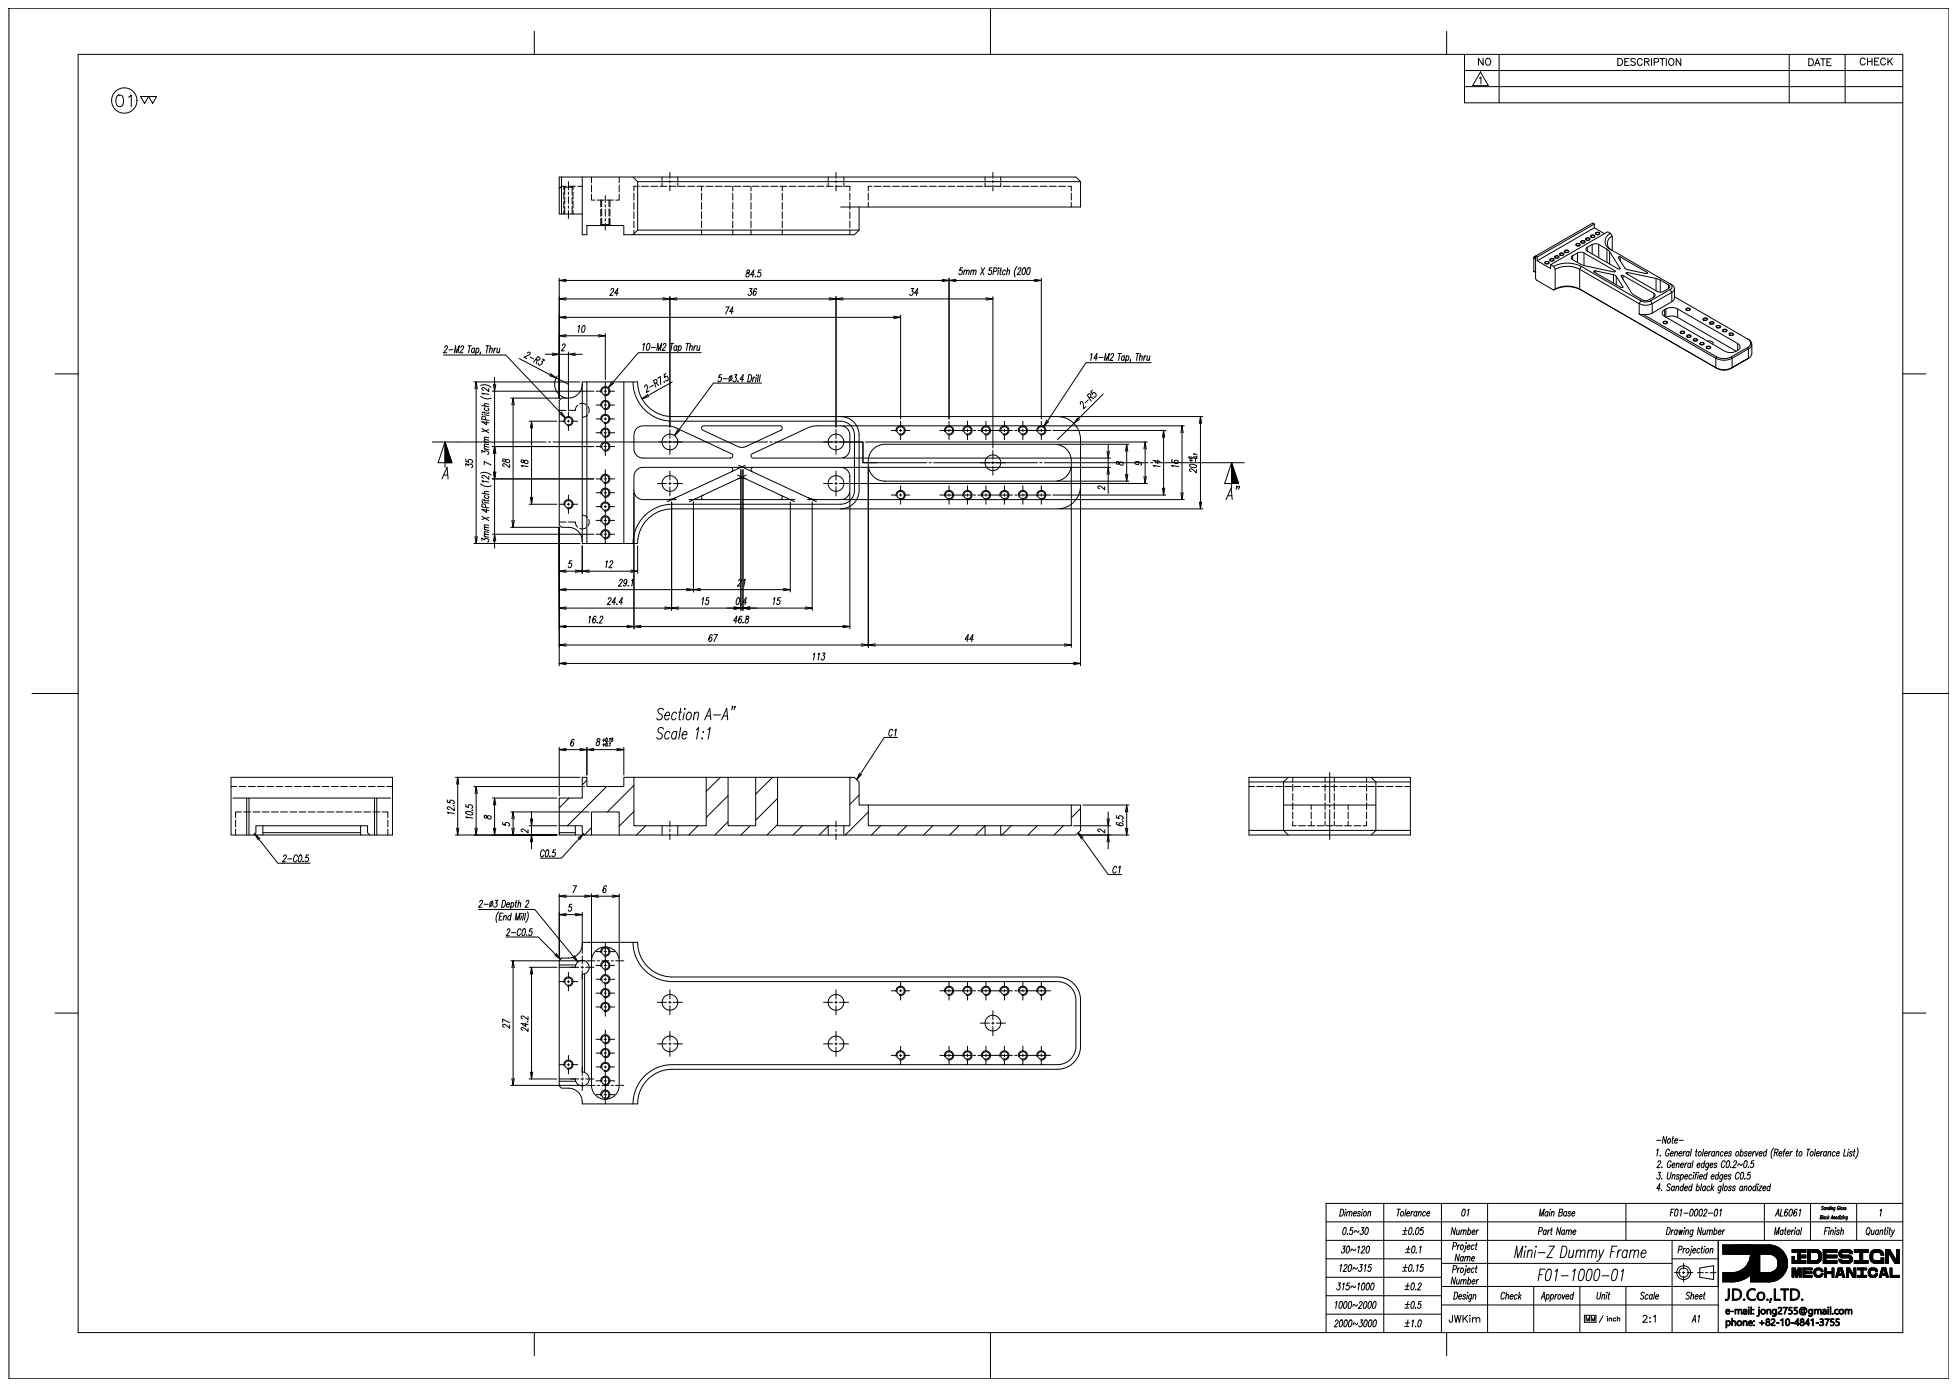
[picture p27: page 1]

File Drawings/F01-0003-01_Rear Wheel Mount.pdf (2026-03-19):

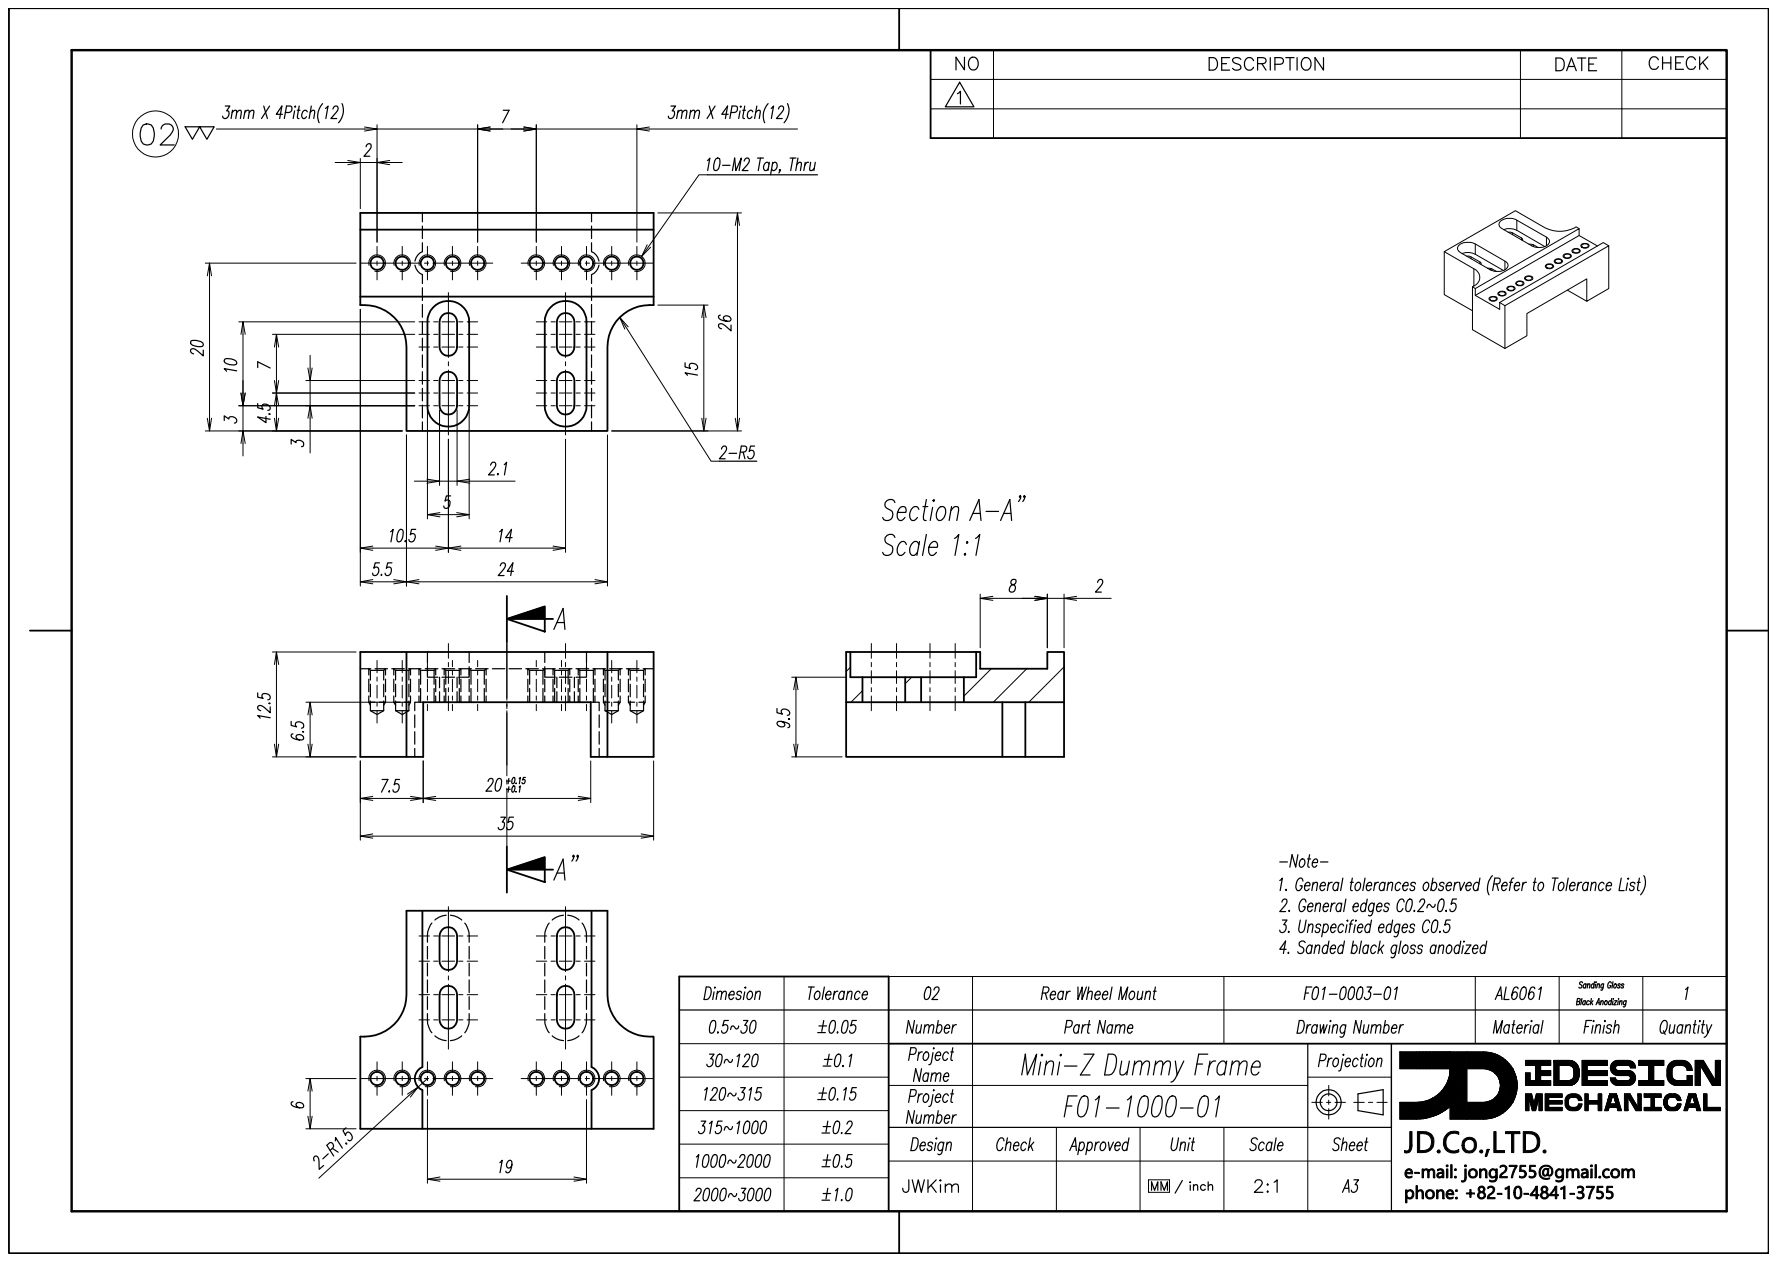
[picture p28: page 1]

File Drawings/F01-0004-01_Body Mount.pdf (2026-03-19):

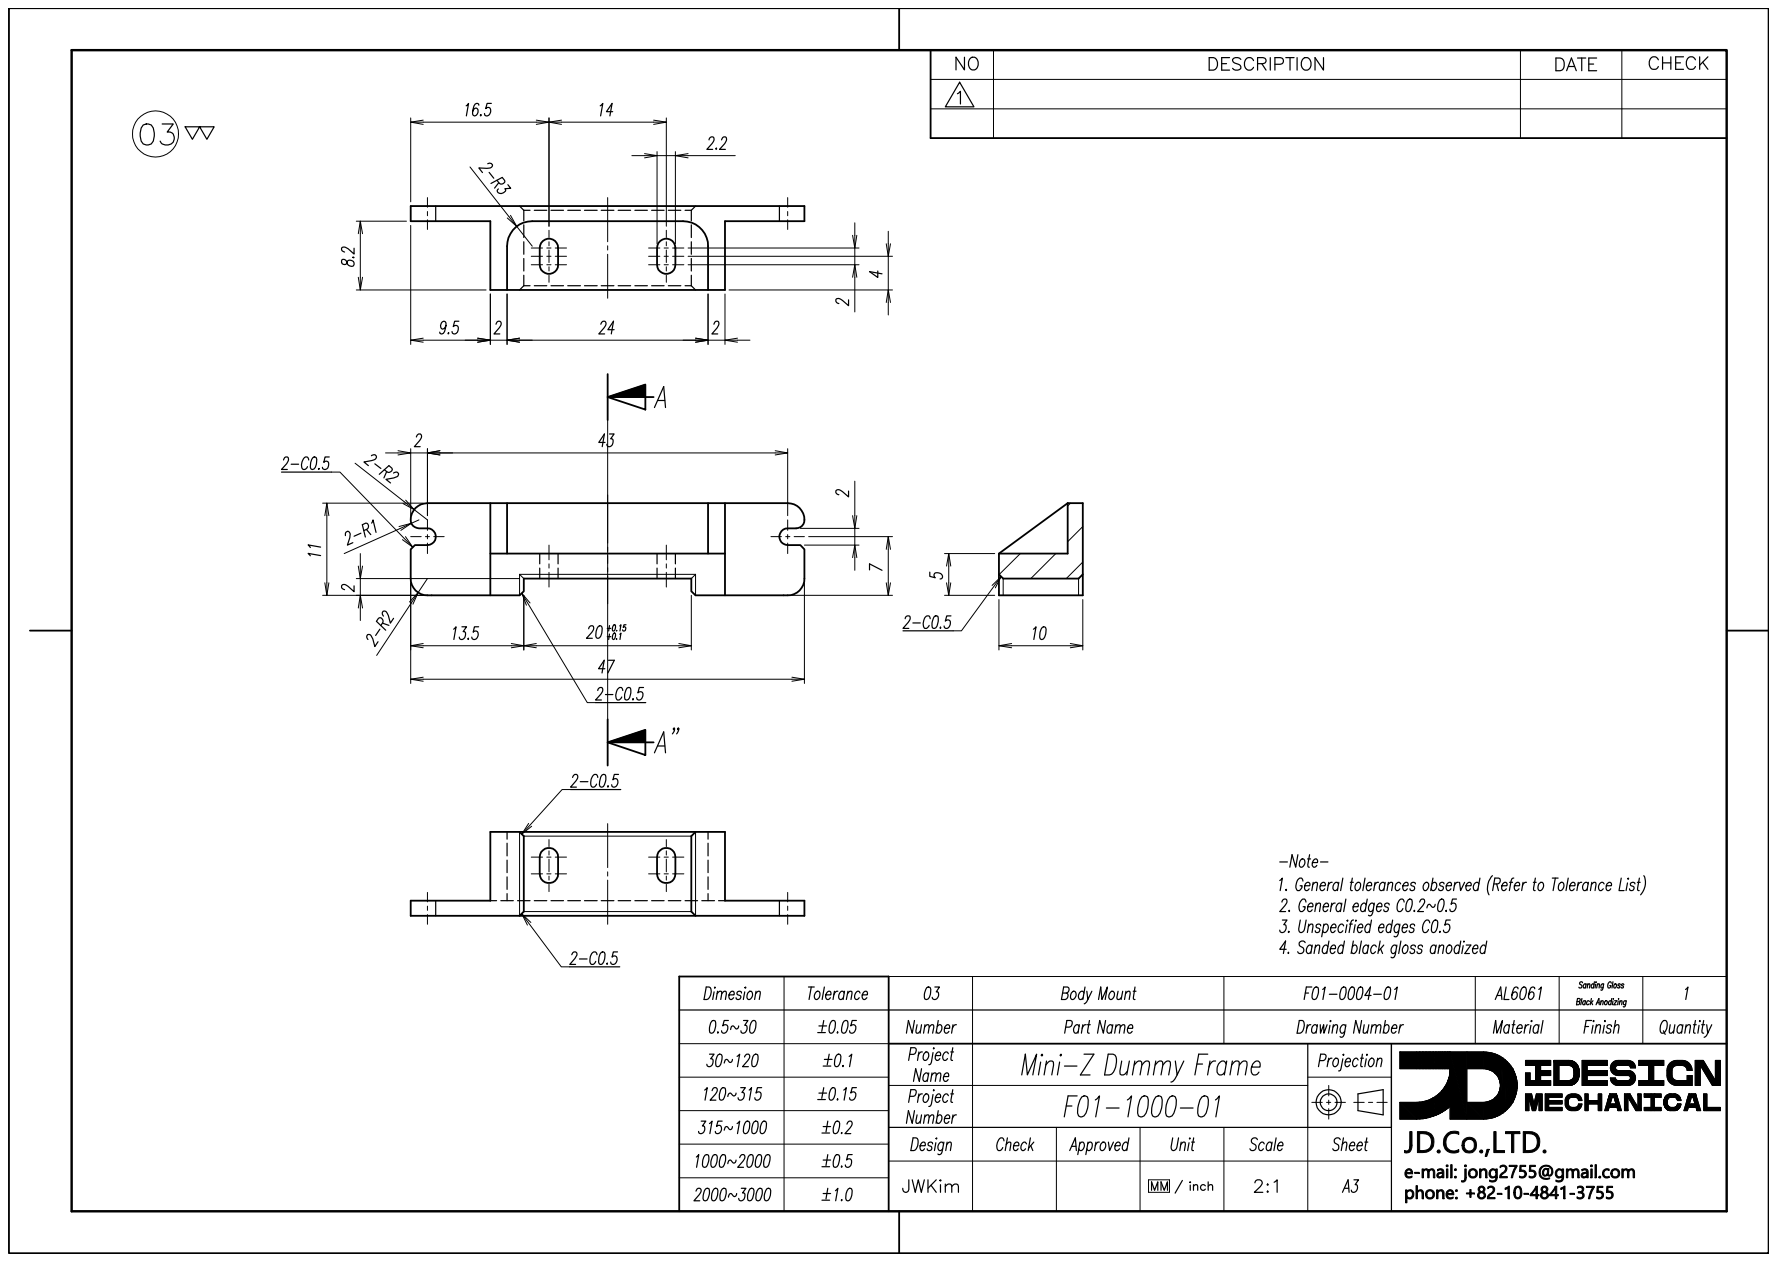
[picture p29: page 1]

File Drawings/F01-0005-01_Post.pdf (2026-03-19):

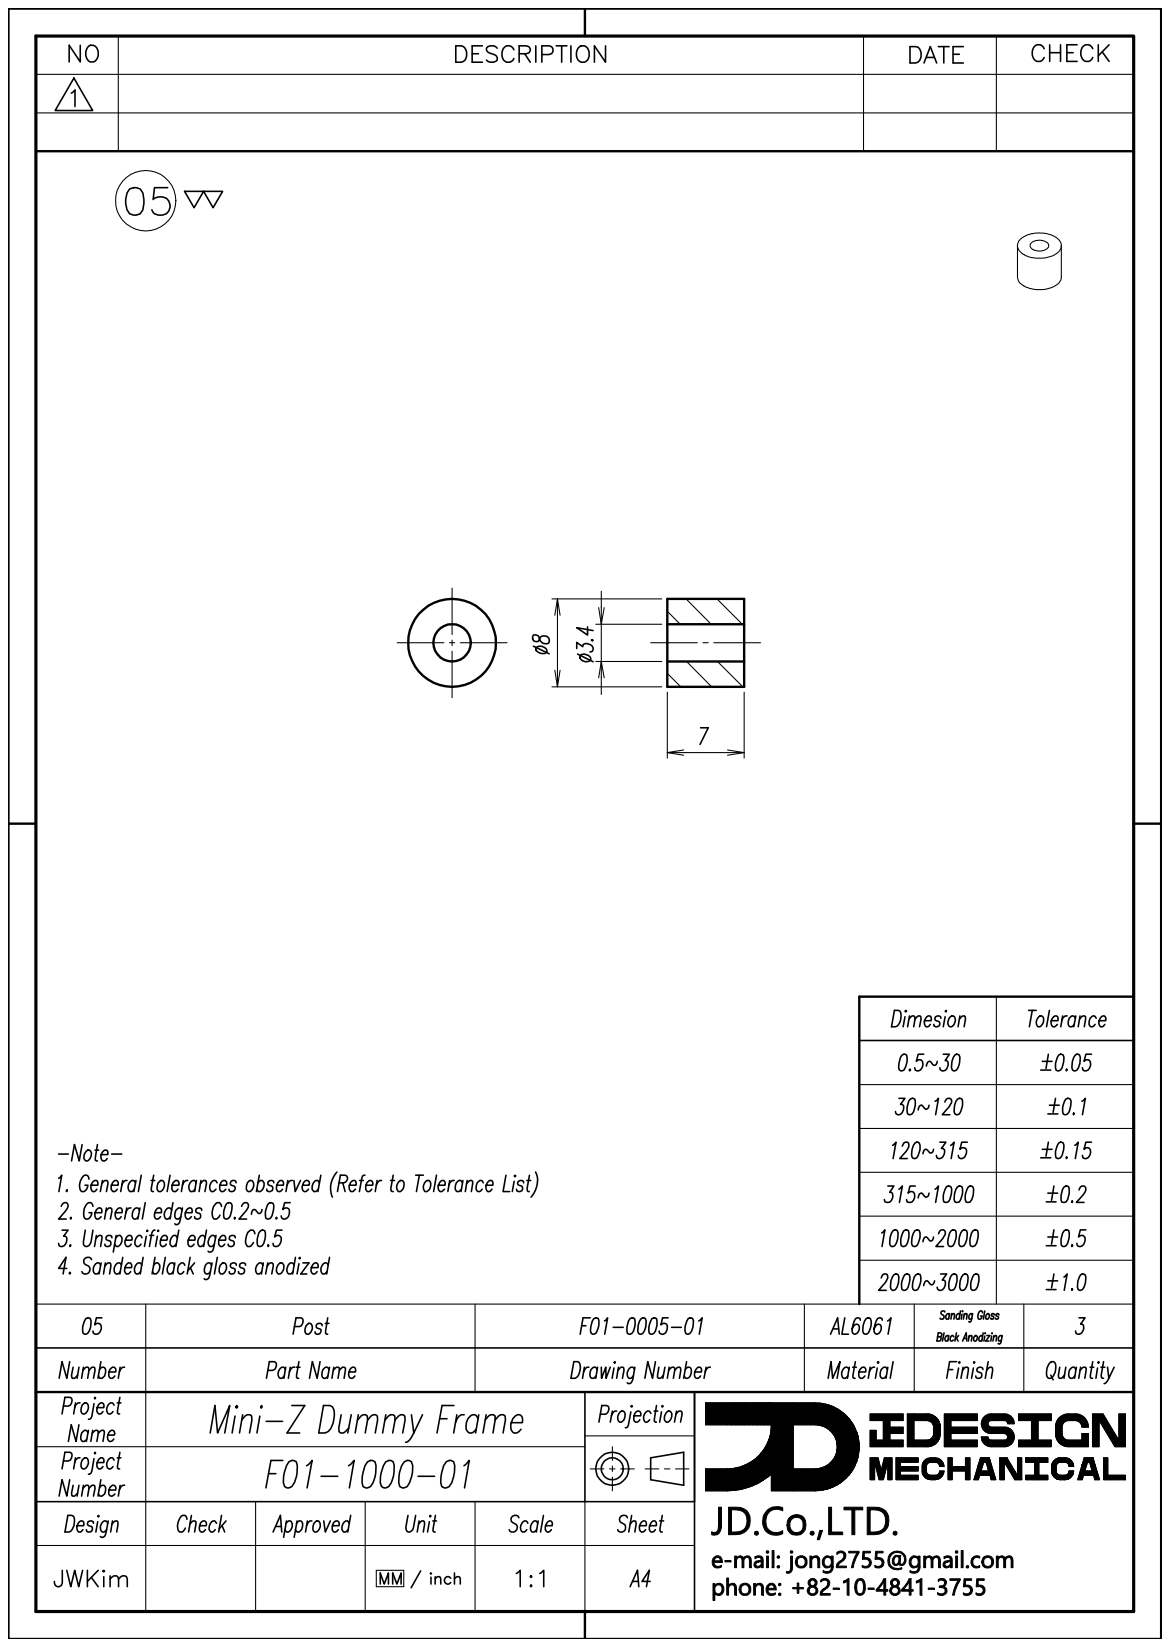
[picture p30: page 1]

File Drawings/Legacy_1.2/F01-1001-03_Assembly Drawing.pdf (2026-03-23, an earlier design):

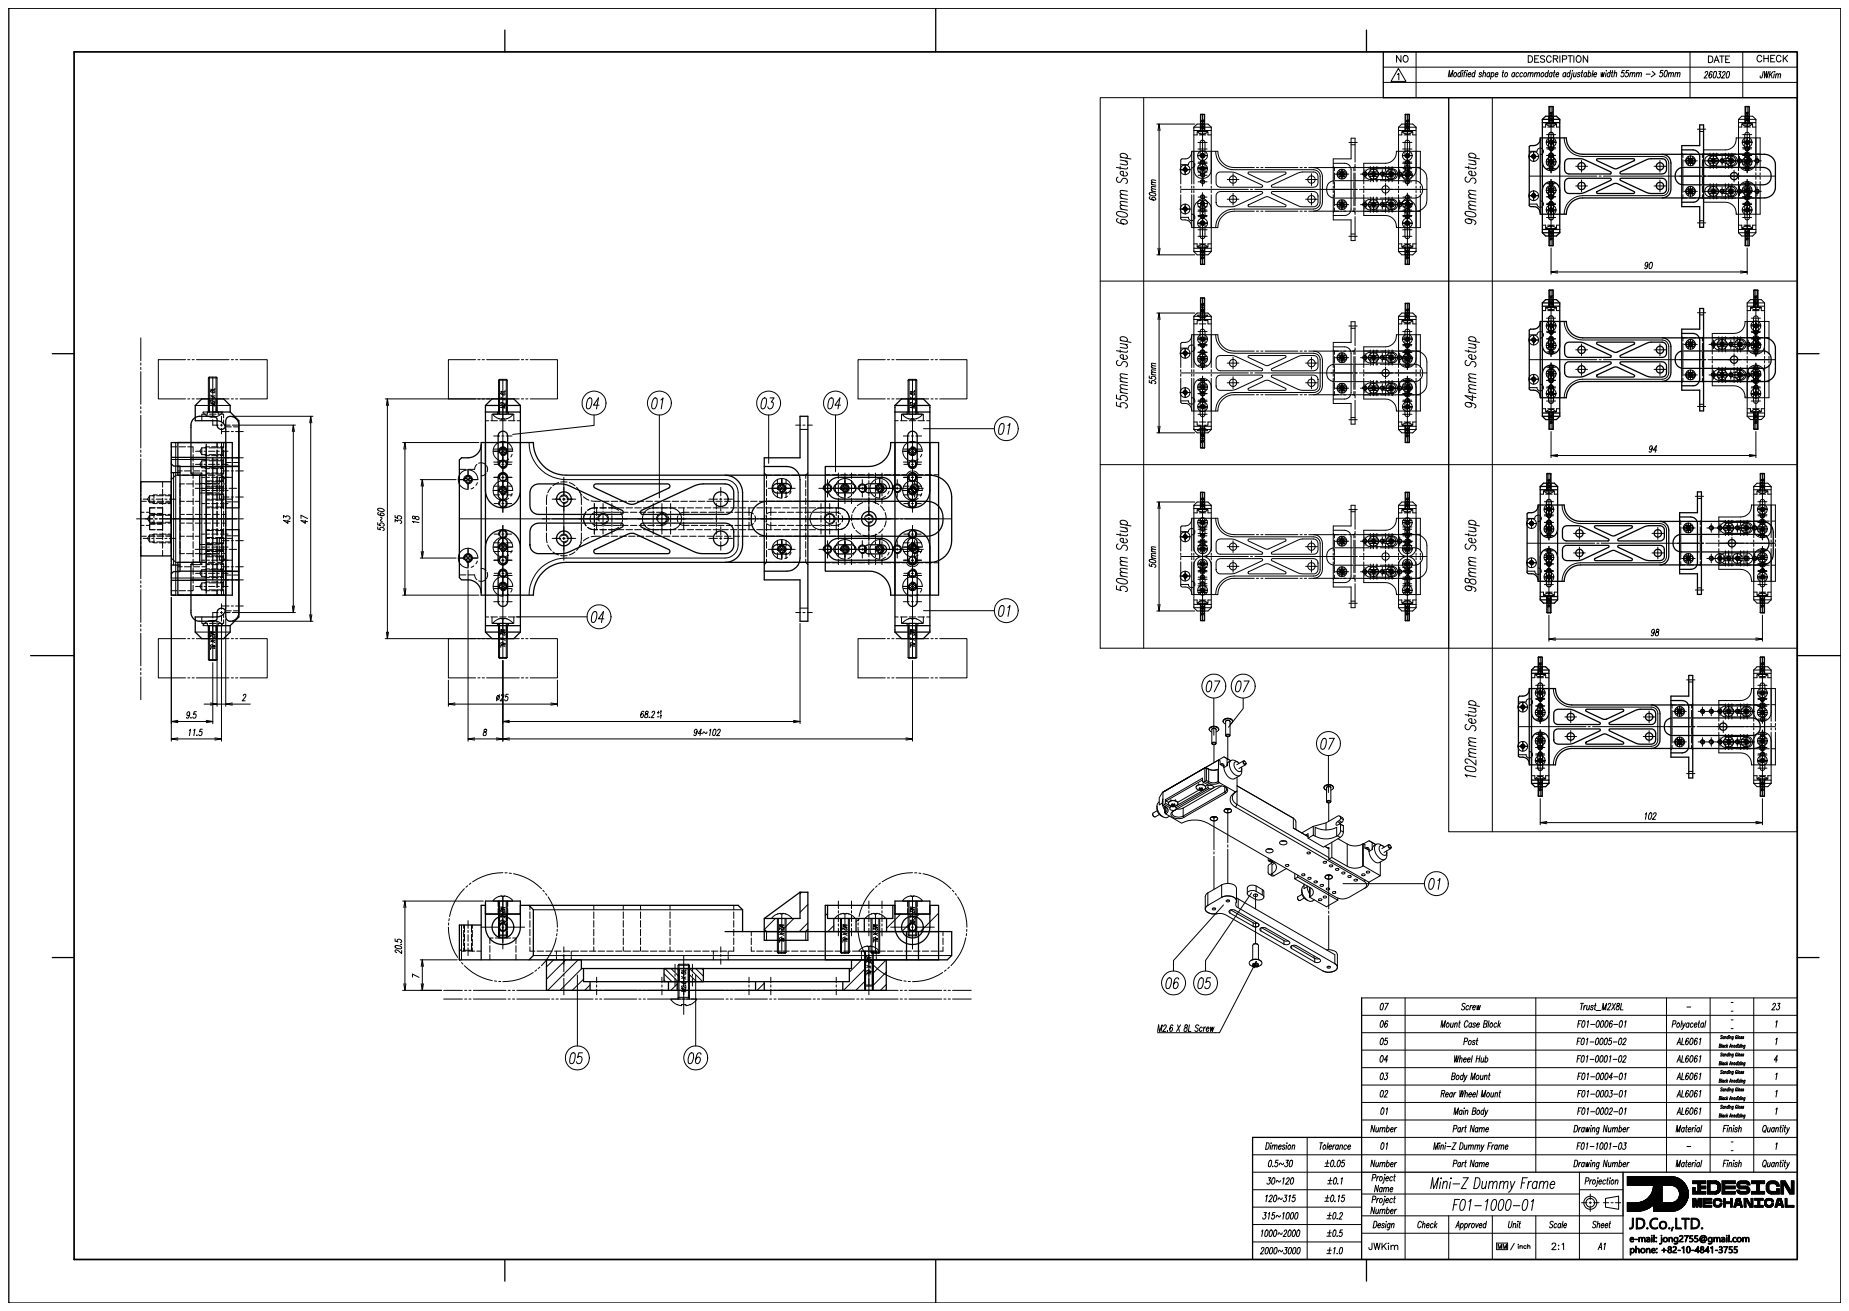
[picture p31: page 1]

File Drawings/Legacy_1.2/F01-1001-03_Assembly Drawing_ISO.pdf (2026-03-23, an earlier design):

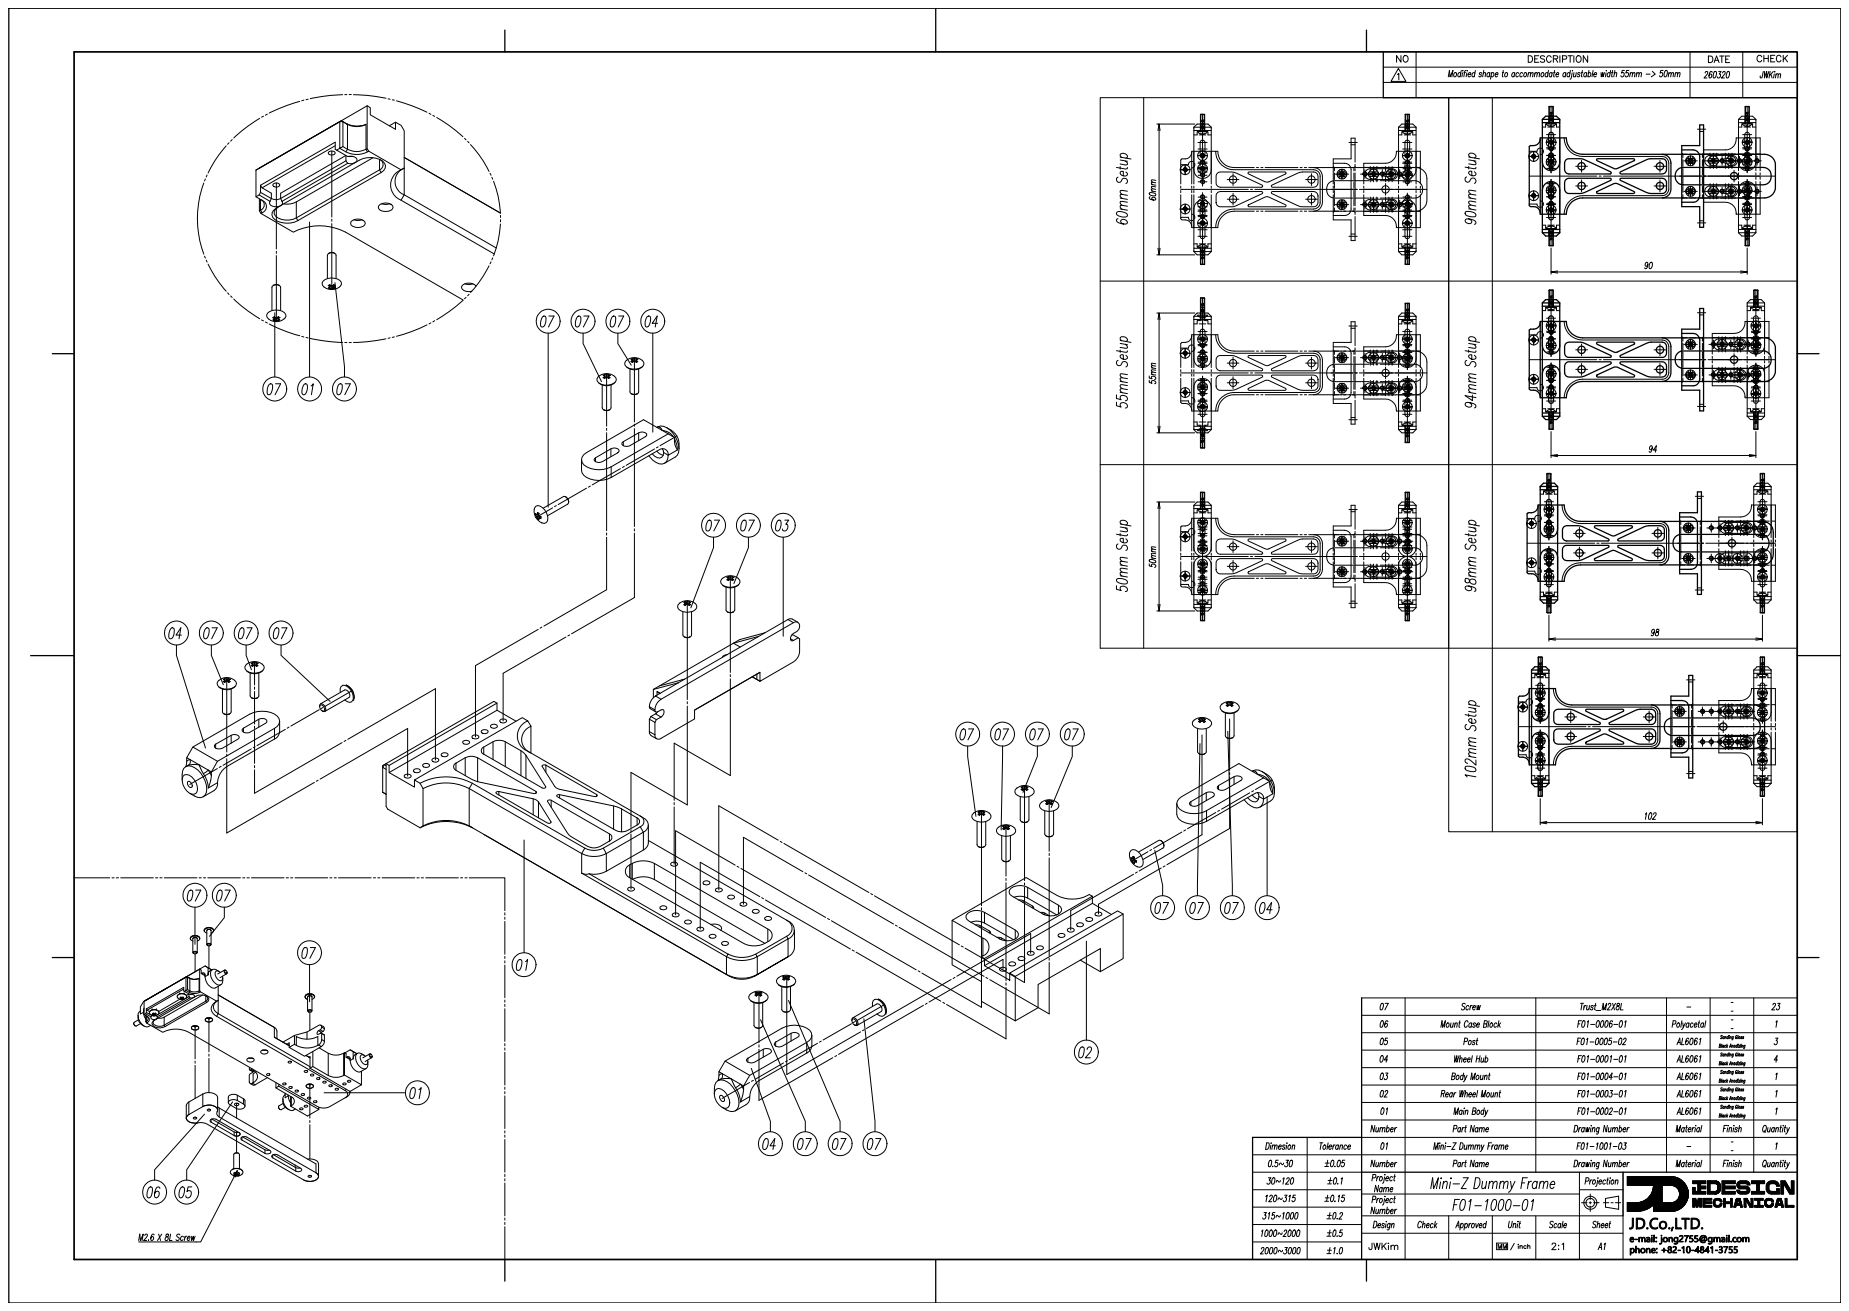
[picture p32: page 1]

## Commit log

2026-03-19 Fix image filename for Dummy Frame Layout
    Updated image reference for the Dummy Frame Layout.
2026-03-19 Fix image captions in README
    Updated image captions for dummy frame layout.
2026-03-19 Enhance README with 3D printing guidelines
    Added recommended print settings and assembly notes for 3D printing.
2026-03-19 Enhance README with CAD collaboration details
    Added section on CAD collaboration and STEP files.
2026-03-19 Add assembly and setup guide to README
    Added assembly and setup guide with images.
2026-03-19 Update license section and image filename
    Reorganized license section and fixed image filename case.
2026-03-23 Add Legacy_1.1/F01-0001-01.STEP file
    [F01-0001-01.STEP]
2026-03-23 Rename STEP File/F01-0001-02.STEP to STEP File/Legacy_1.1 /F01-0001-02.STEP
    [F01-0001-02.STEP]
2026-03-23 Rename STEP File/F01-0002-01.STEP to STEP File/Legacy_1.1/F01-0002-01.STEP
    [F01-0002-01.STEP]
2026-03-23 Rename STEP File/F01-0003-01.STEP to STEP File/Legacy_1.1/F01-0003-01.STEP
    [F01-0003-01.STEP]
2026-03-23 Add Legacy STEP file F01-0004-03_47mm
    [F01-0004-03_47mm.STEP]
2026-03-23 Rename STEP File/F01-0005-01.STEP to STEP File/Legacy_1.1/F01-0005-01.STEP
    [F01-0005-01.STEP]
2026-03-23 Rename Drawings/F01-0003-01_Rear Wheel Mount.pdf to Drawings/Legacy_1.1/F01-0003-01_Rear Wheel Mount.pdf
2026-03-23 Rename Drawings/F01-0004-01_Body Mount.pdf to Drawings/Legacy_1.1/F01-0004-01_Body Mount.pdf
